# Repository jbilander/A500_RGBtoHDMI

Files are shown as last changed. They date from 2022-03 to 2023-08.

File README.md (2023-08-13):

# A500_RGBtoHDMI
My RGBtoHDMI-adapter-board design for A500.

***

<a href="images/A500_RGBtoHDMI_pic1.png">
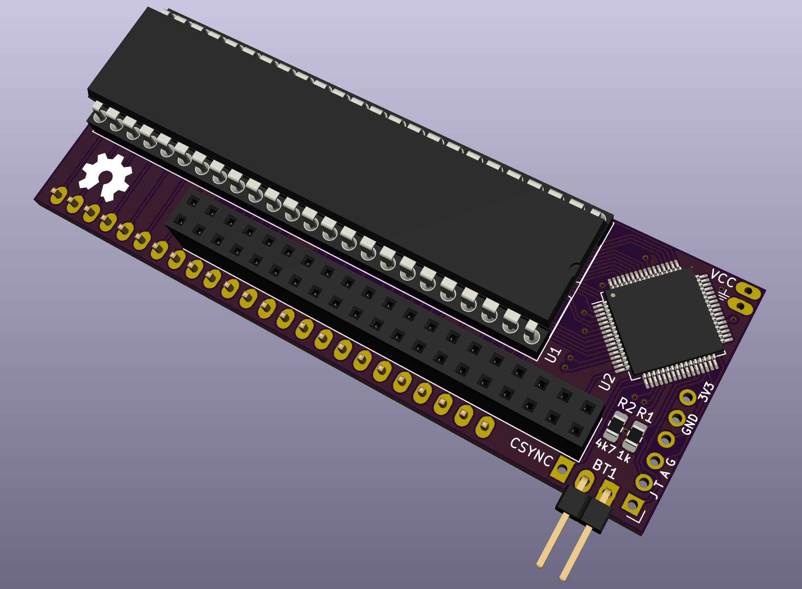
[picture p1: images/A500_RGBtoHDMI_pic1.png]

</a>
<a href="images/A500_RGBtoHDMI_pic2.png">
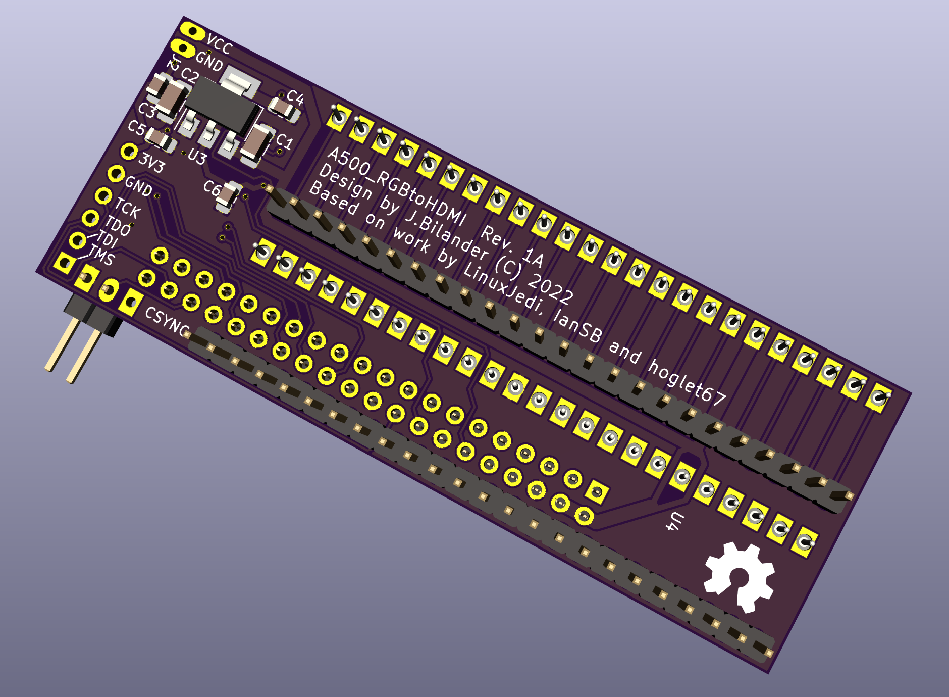
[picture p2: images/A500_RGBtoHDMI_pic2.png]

</a>
<br />
<a href="images/A500_RGBtoHDMI_pic5.png">
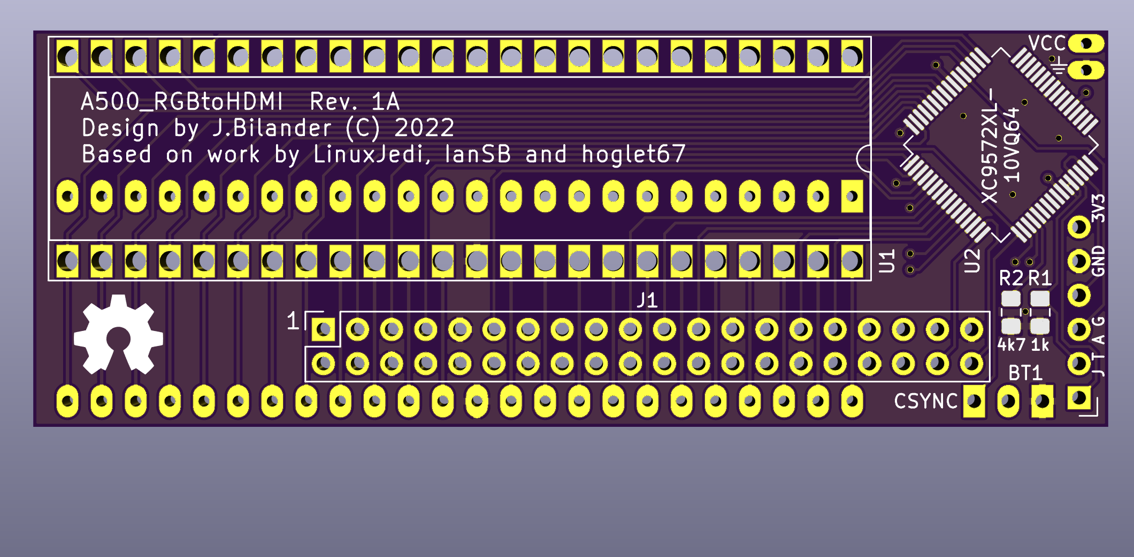
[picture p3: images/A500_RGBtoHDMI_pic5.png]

</a>
<a href="images/A500_RGBtoHDMI_pic6.png">
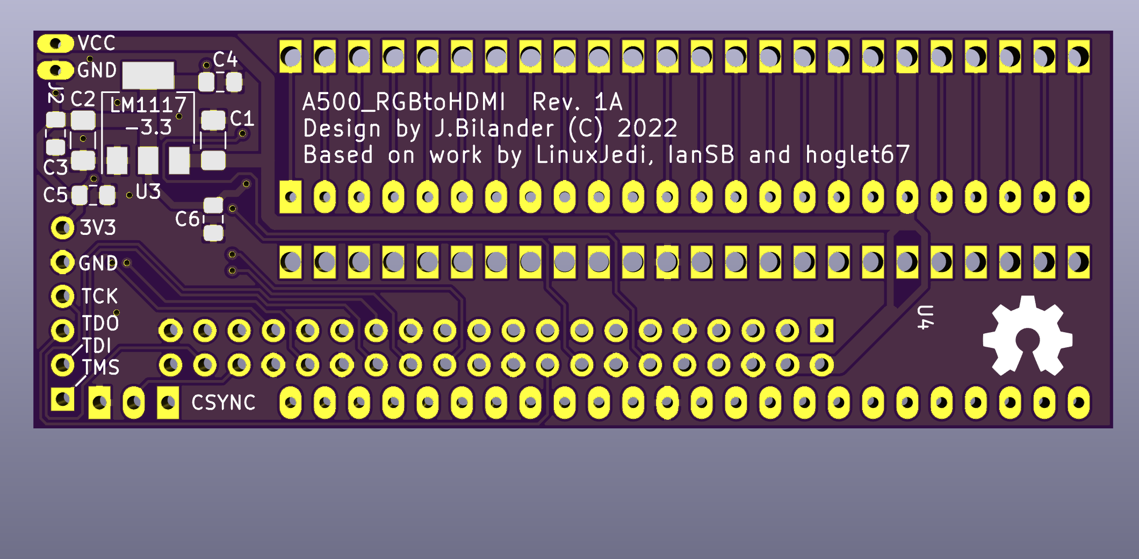
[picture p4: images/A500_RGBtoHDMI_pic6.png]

</a>

***

<a href="images/A500_RGBtoHDMI_pic8.png">
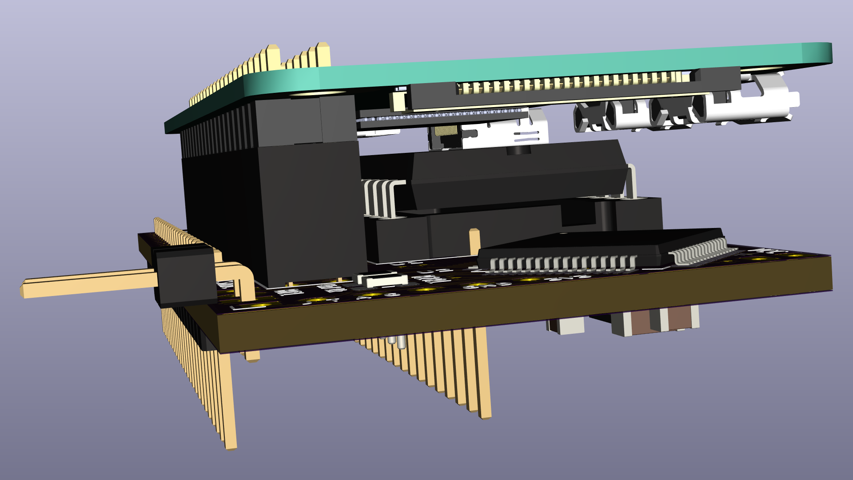
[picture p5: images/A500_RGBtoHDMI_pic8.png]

</a>
<a href="images/A500_RGBtoHDMI_pic9.png">
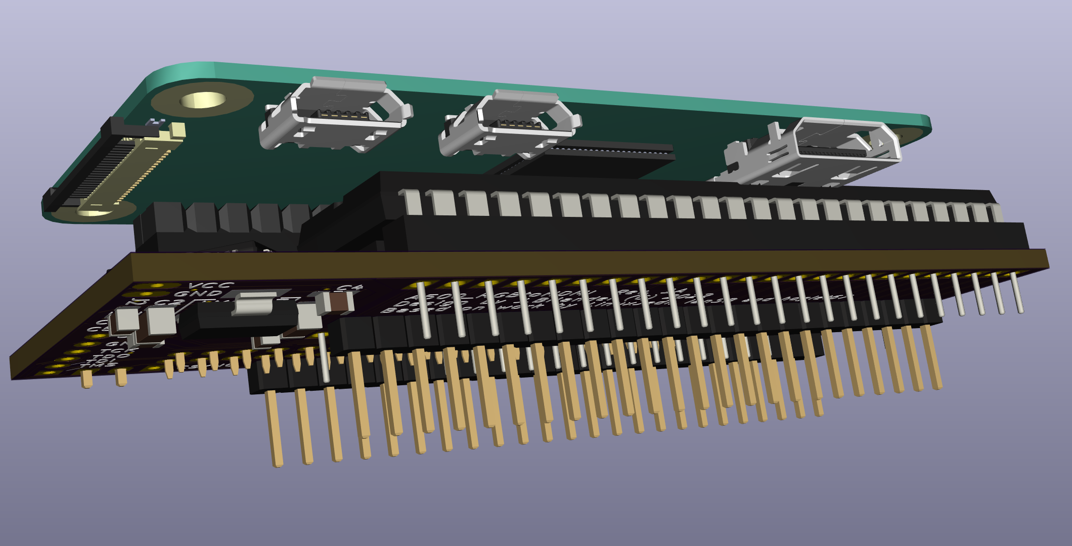
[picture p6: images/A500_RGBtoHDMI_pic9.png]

</a>
<br />
<a href="images/A500_RGBtoHDMI_pic10.png">
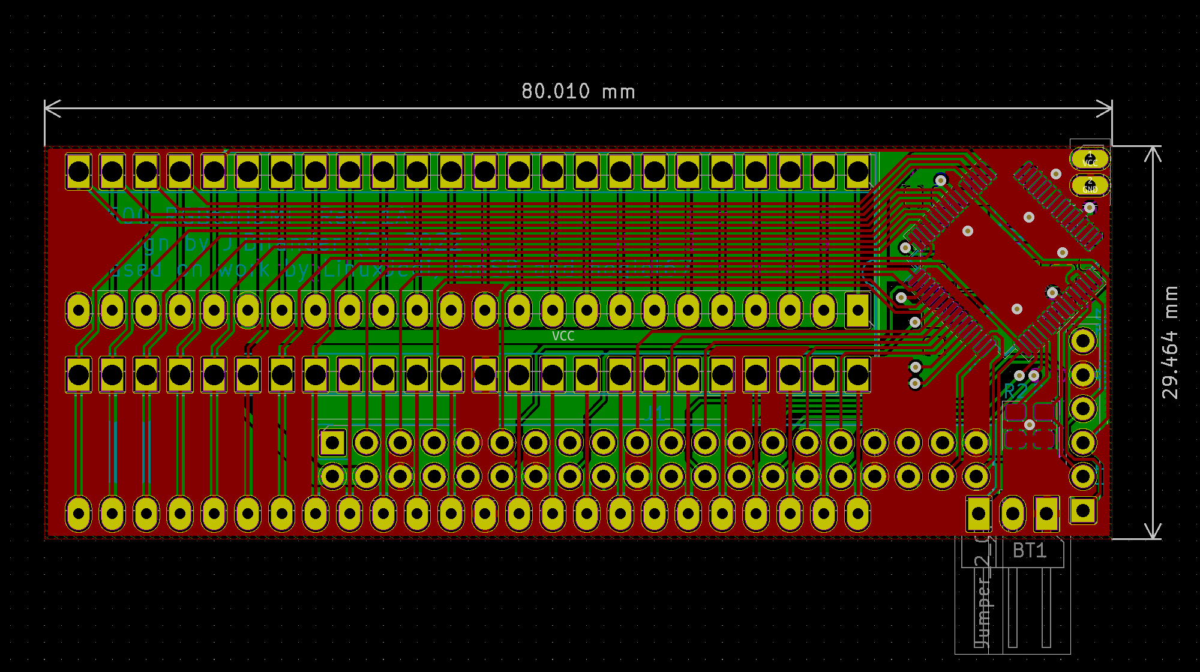
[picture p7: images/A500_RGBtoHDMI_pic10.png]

</a>

***

<a href="images/A500_RGBtoHDMI_pic11.jpg">
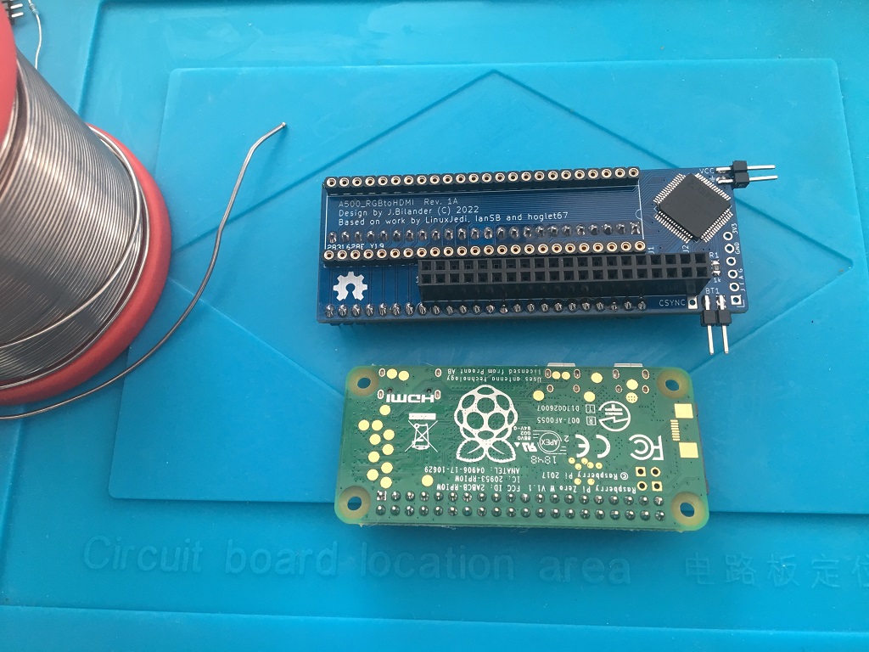
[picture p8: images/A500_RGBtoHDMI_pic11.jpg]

</a>
<a href="images/A500_RGBtoHDMI_pic13.jpg">
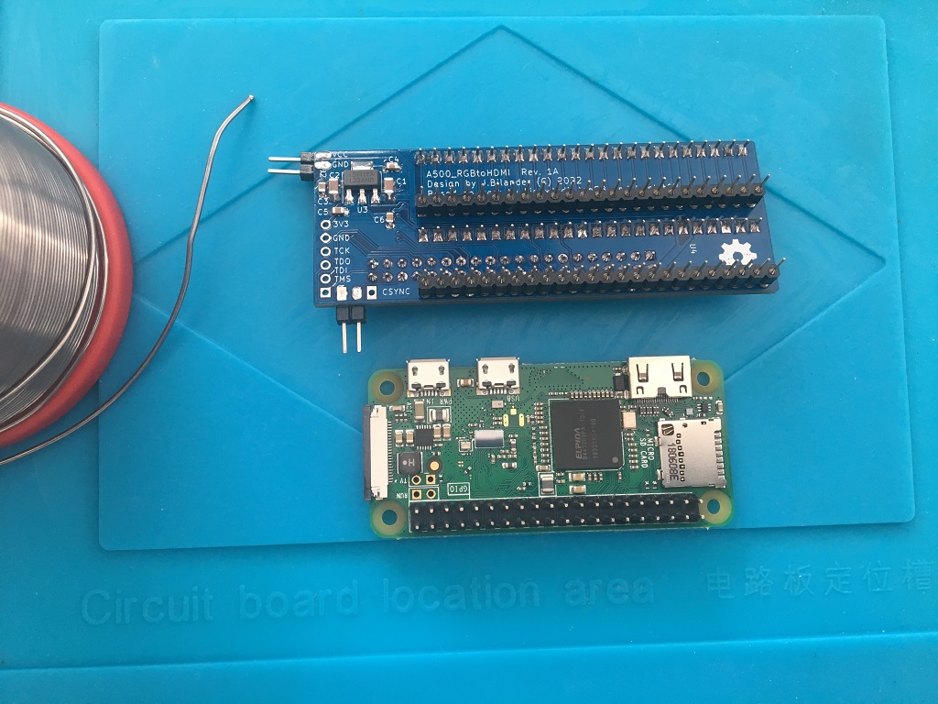
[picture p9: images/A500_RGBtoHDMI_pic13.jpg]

</a>
<a href="images/A500_RGBtoHDMI_pic12.jpg">
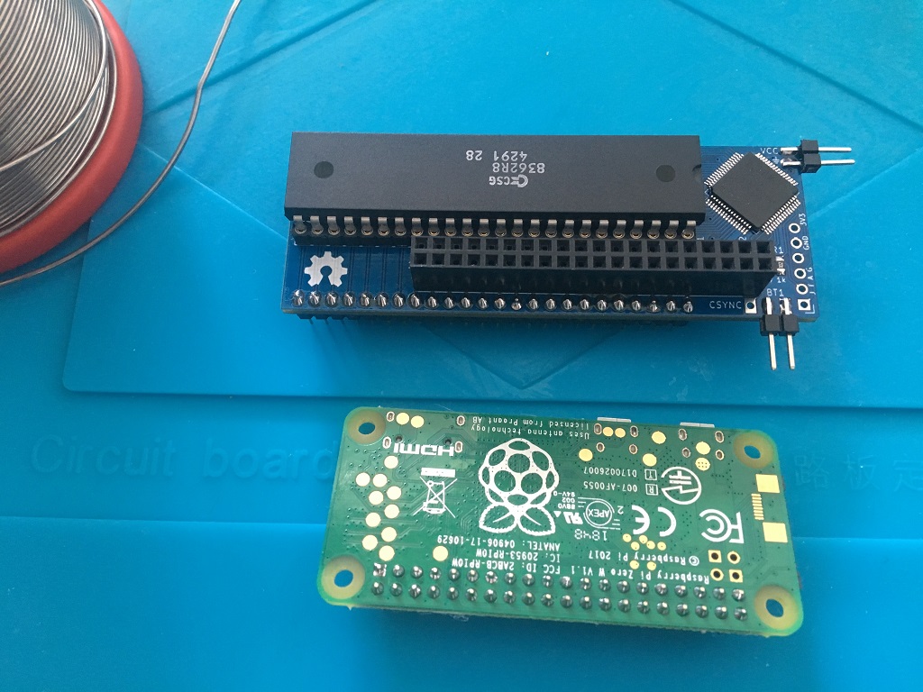
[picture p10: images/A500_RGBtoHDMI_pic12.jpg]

</a>
<br />
<a href="images/A500_RGBtoHDMI_pic14.jpg">
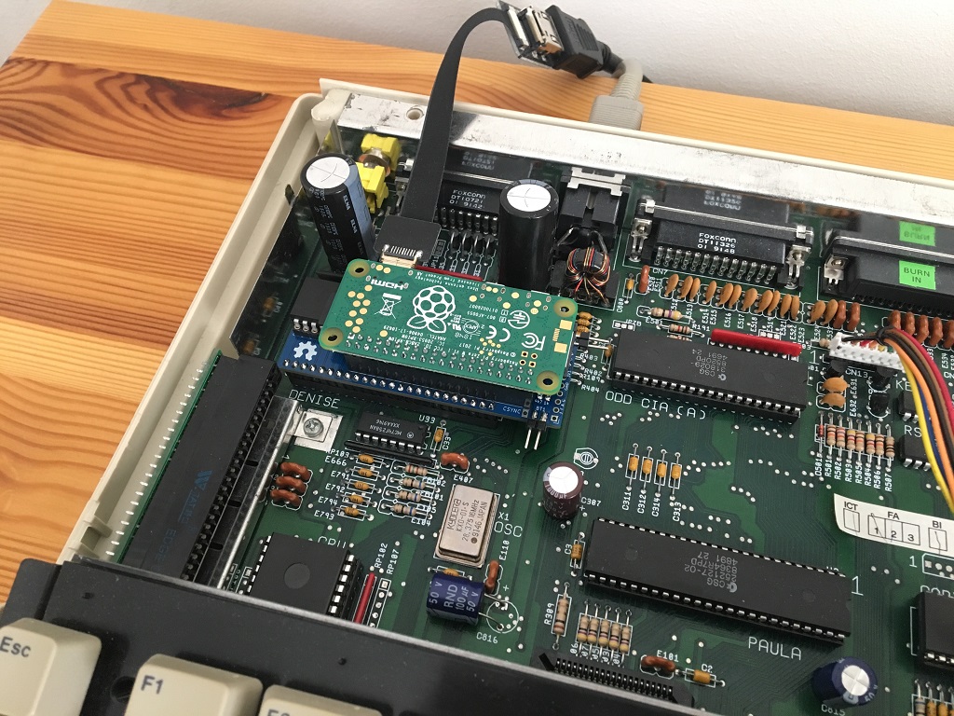
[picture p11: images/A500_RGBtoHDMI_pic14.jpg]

</a>
<a href="images/A500_RGBtoHDMI_pic30.jpg">
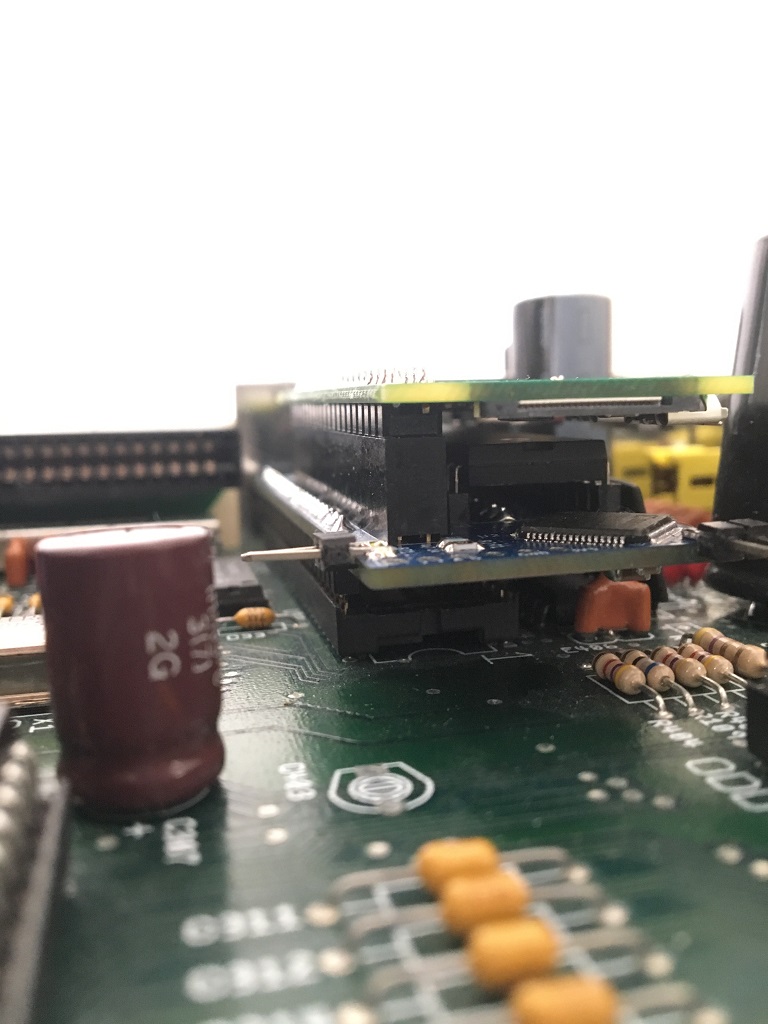
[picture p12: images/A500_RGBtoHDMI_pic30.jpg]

</a>

***

### Build

<a href="images/A500_RGBtoHDMI_pic15.jpg">
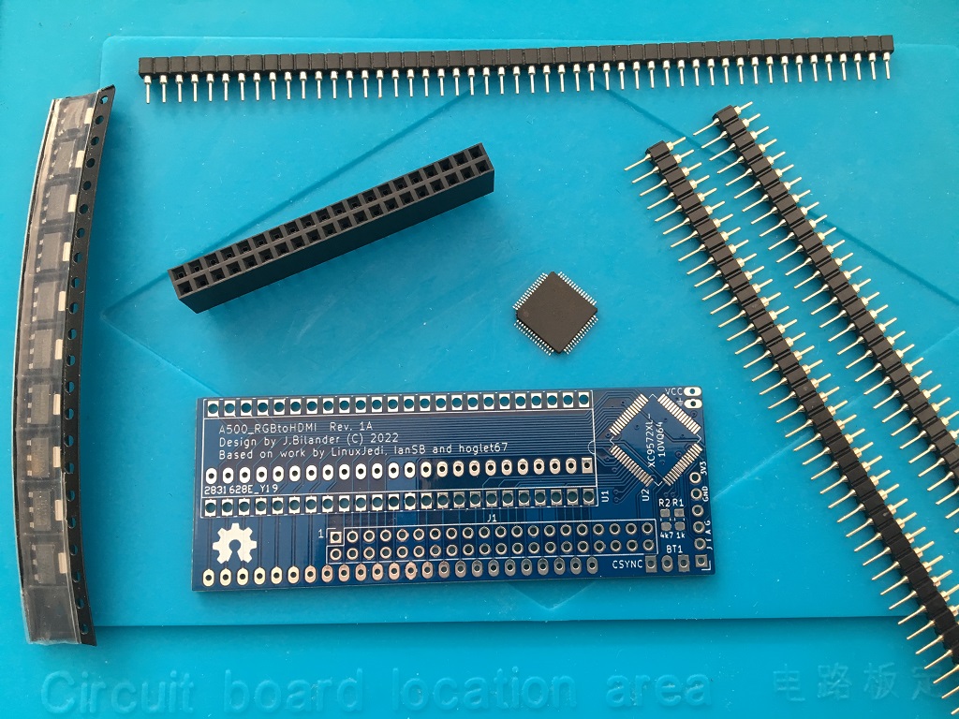
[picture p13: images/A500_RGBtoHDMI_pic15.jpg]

</a>
<a href="images/A500_RGBtoHDMI_pic17.jpg">
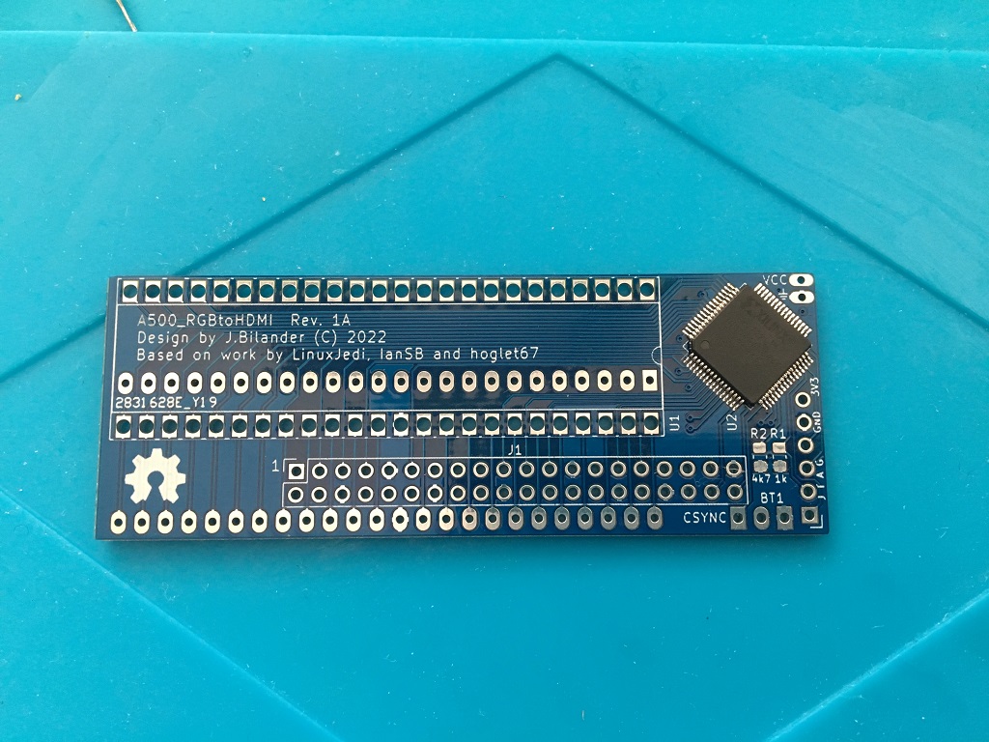
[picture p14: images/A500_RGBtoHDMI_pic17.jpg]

</a>
<a href="images/A500_RGBtoHDMI_pic18.jpg">
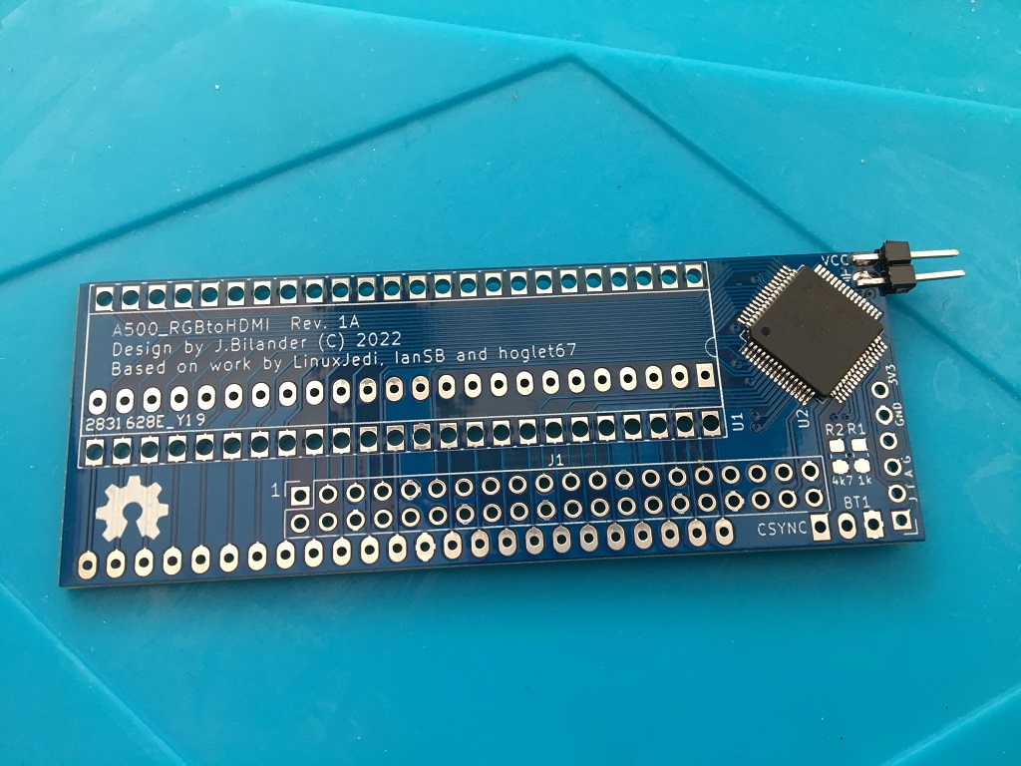
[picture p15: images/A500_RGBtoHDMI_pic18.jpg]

</a>
<br />
<a href="images/A500_RGBtoHDMI_pic19.jpg">
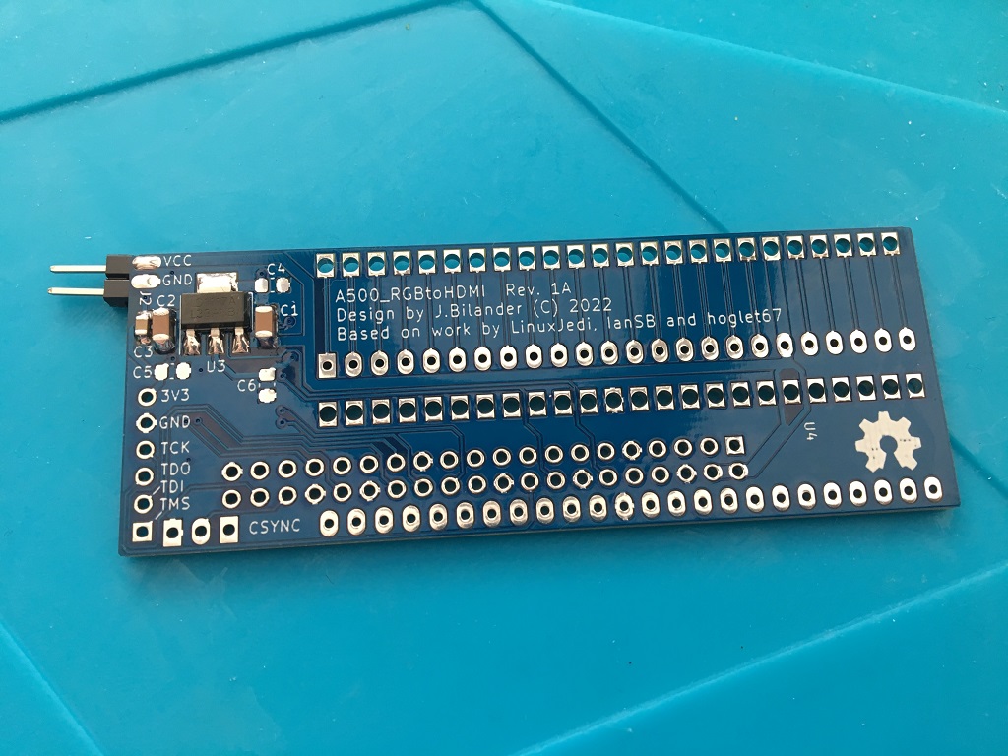
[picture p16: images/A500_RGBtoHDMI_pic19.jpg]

</a>
<a href="images/A500_RGBtoHDMI_pic20.jpg">
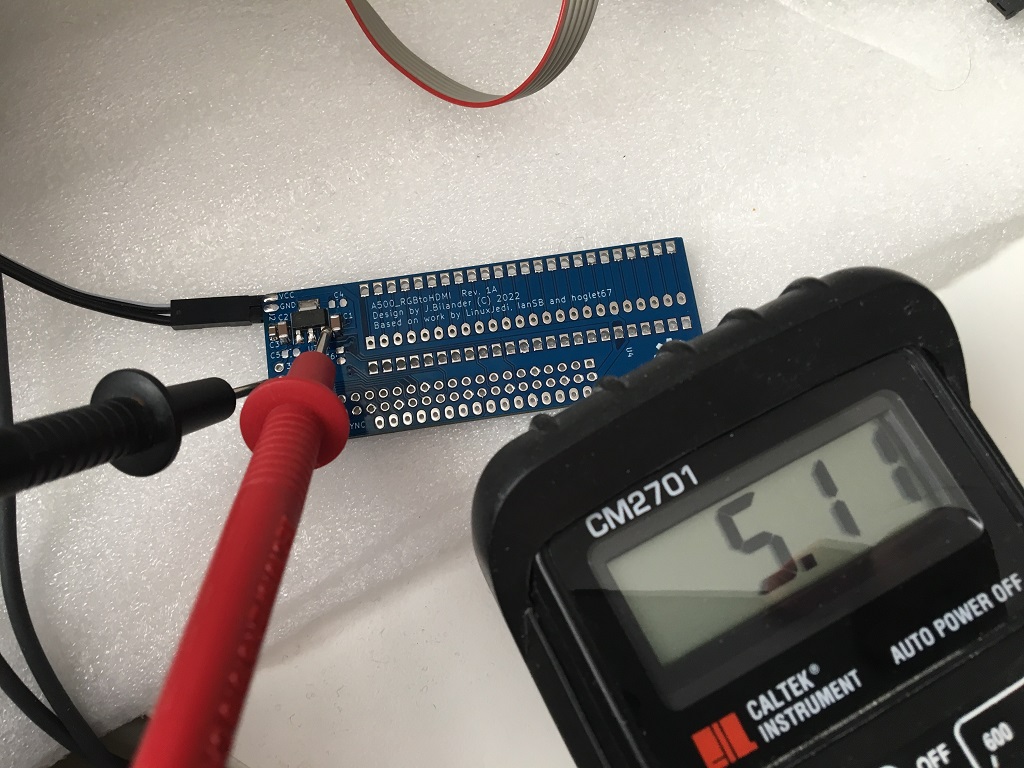
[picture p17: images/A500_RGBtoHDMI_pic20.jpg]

</a>
<a href="images/A500_RGBtoHDMI_pic21.jpg">
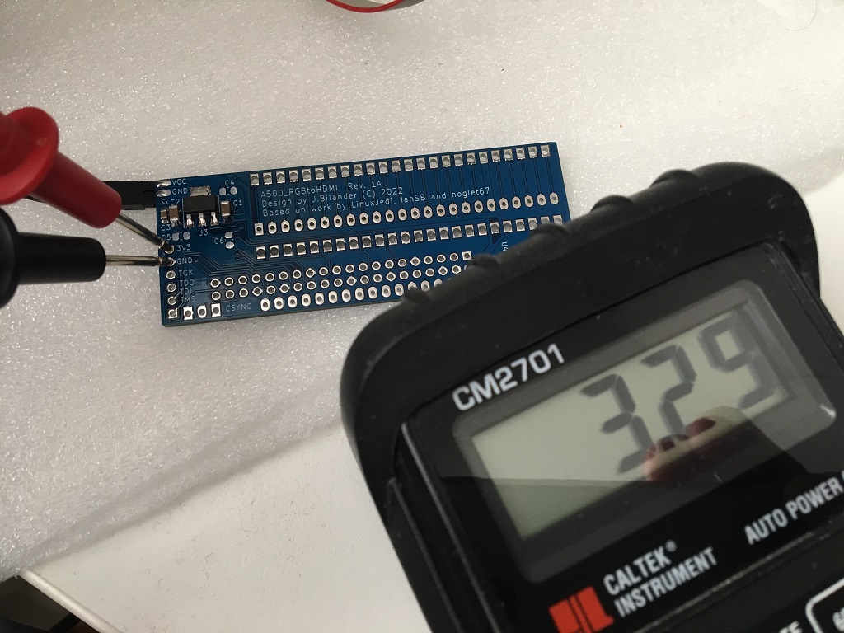
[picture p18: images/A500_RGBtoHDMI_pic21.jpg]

</a>
<br />
<a href="images/A500_RGBtoHDMI_pic22.jpg">
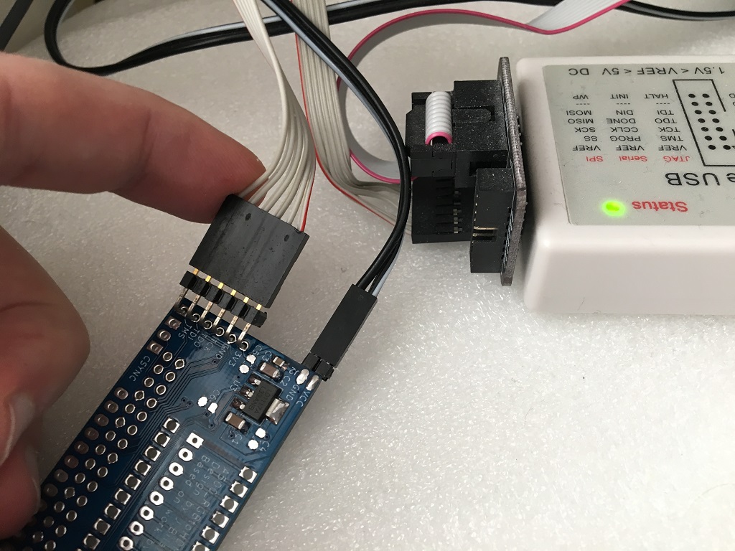
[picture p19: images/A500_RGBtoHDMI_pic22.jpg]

</a>
<a href="images/A500_RGBtoHDMI_pic23.jpg">
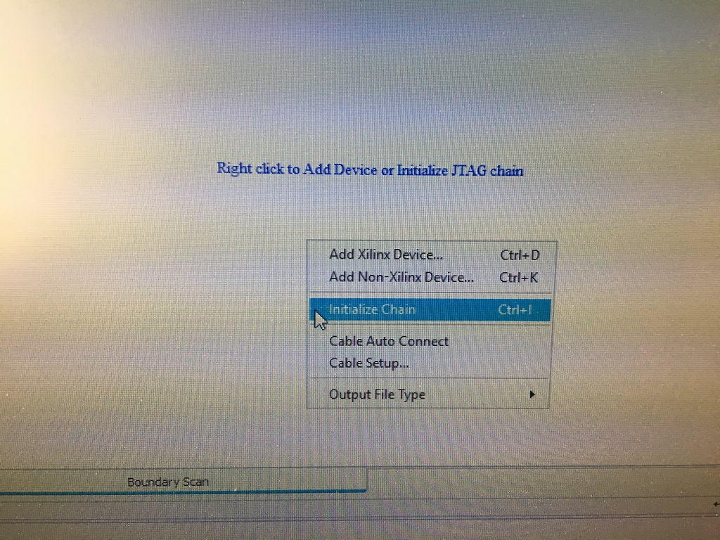
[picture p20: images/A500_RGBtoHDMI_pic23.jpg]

</a>
<a href="images/A500_RGBtoHDMI_pic24.jpg">
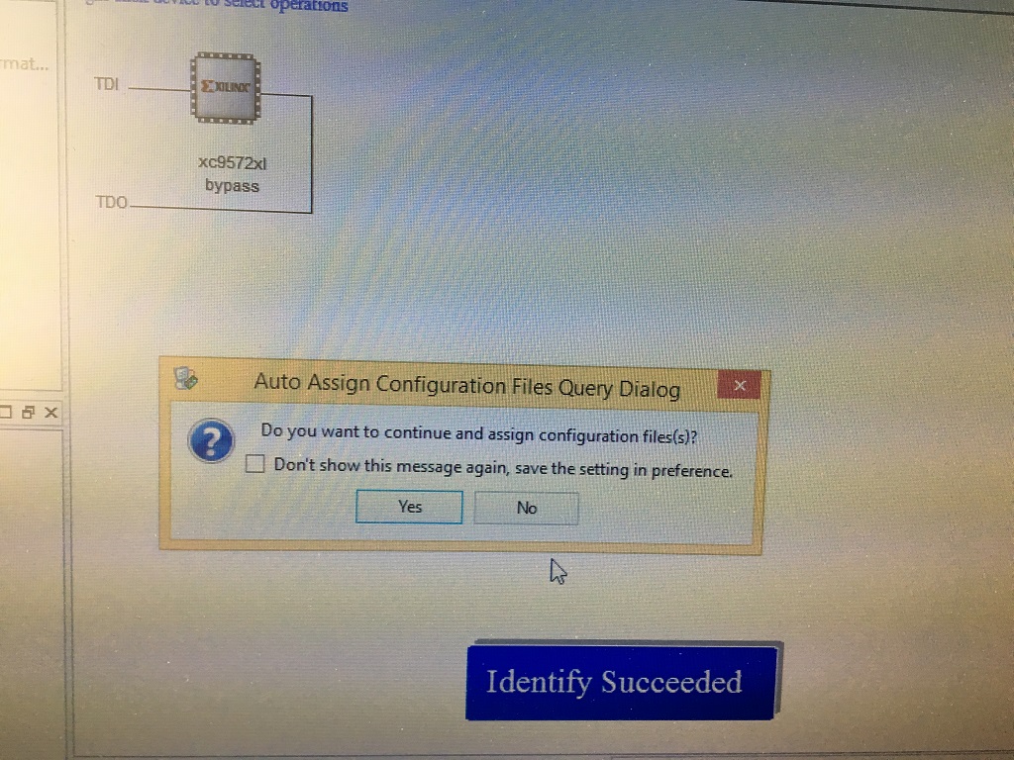
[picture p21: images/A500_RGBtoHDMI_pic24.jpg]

</a>
<br />
<a href="images/A500_RGBtoHDMI_pic25.jpg">
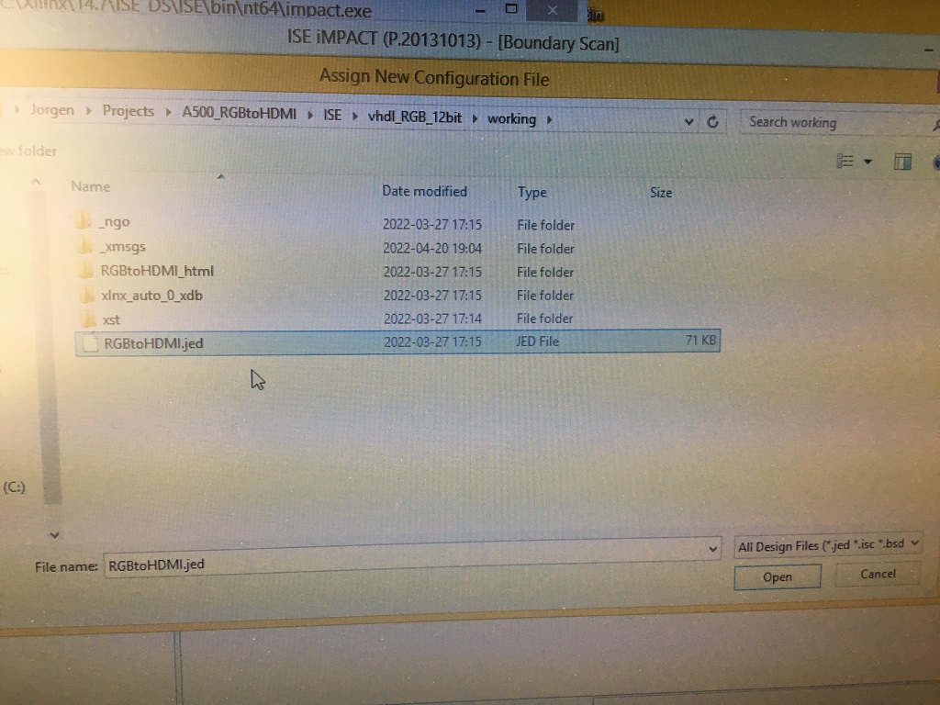
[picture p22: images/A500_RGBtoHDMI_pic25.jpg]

</a>
<a href="images/A500_RGBtoHDMI_pic26.jpg">
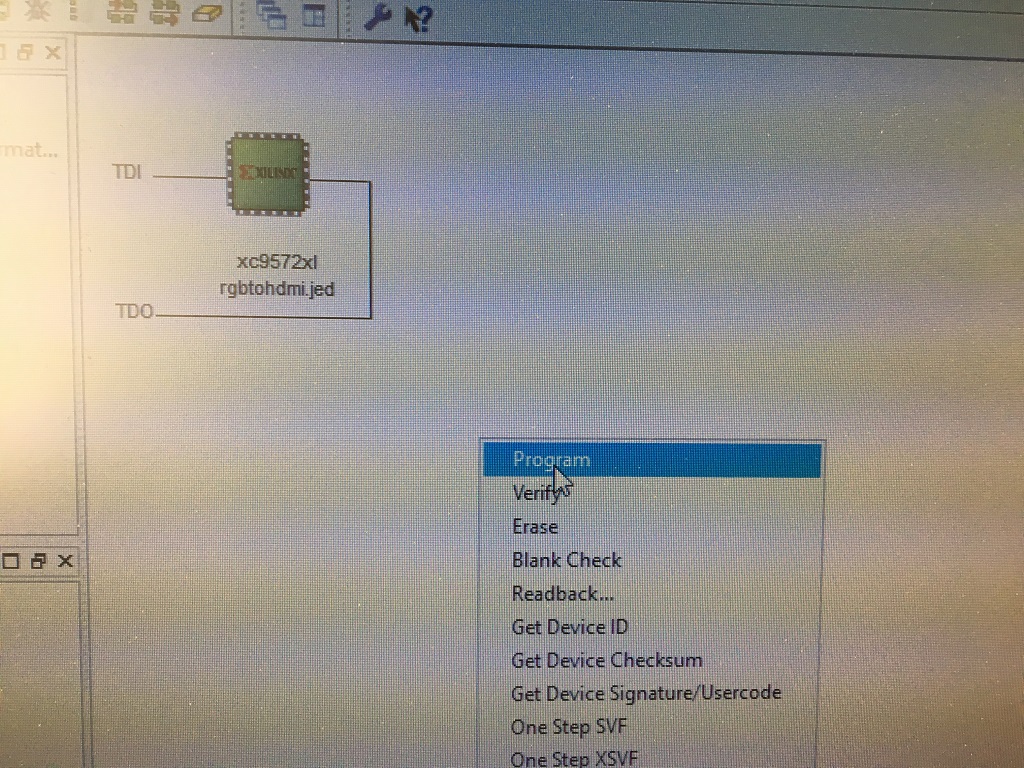
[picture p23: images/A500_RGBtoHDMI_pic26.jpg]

</a>
<a href="images/A500_RGBtoHDMI_pic27.jpg">
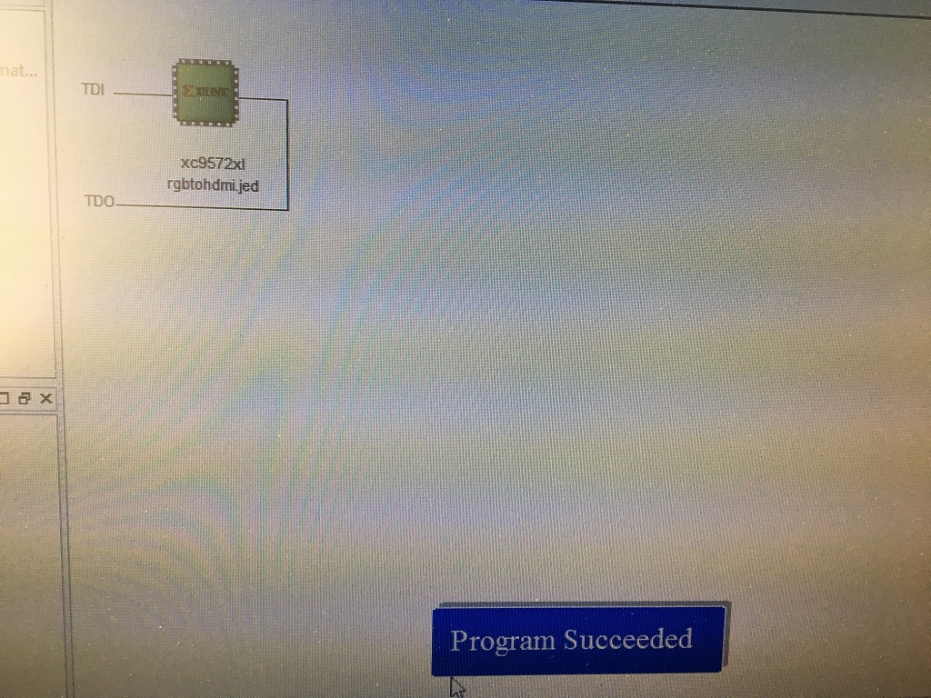
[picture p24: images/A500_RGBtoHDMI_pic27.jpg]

</a>
<br />
<a href="images/A500_RGBtoHDMI_pic28.jpg">
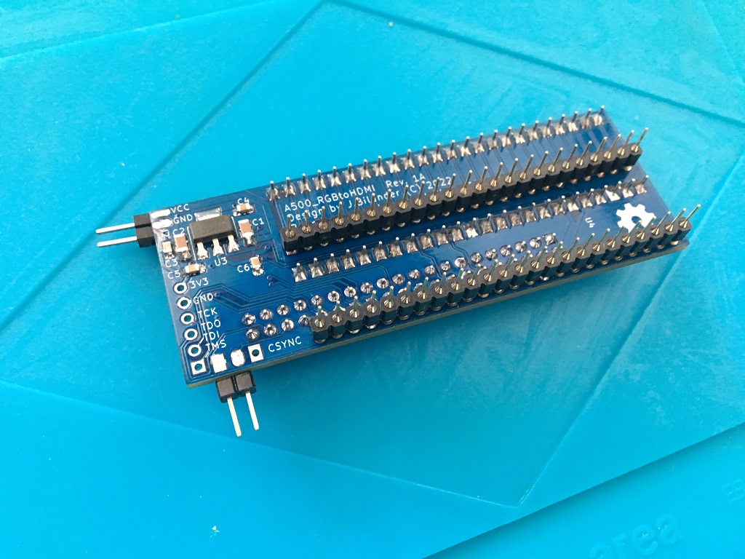
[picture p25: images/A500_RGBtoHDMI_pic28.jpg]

</a>
<a href="images/A500_RGBtoHDMI_pic29.jpg">
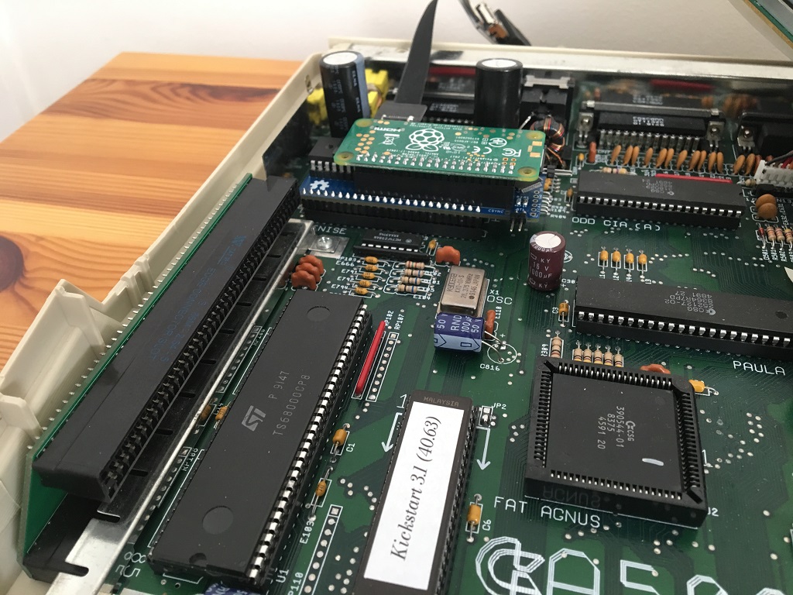
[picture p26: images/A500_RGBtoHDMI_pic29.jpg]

</a>
<a href="images/A500_RGBtoHDMI_pic31.jpg">
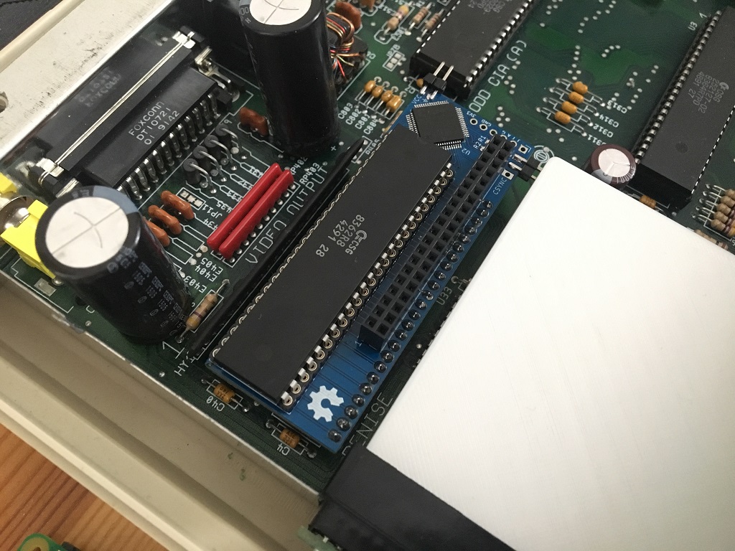
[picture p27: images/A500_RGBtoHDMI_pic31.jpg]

</a>
<br />
<a href="images/A500_RGBtoHDMI_pic32.jpg">
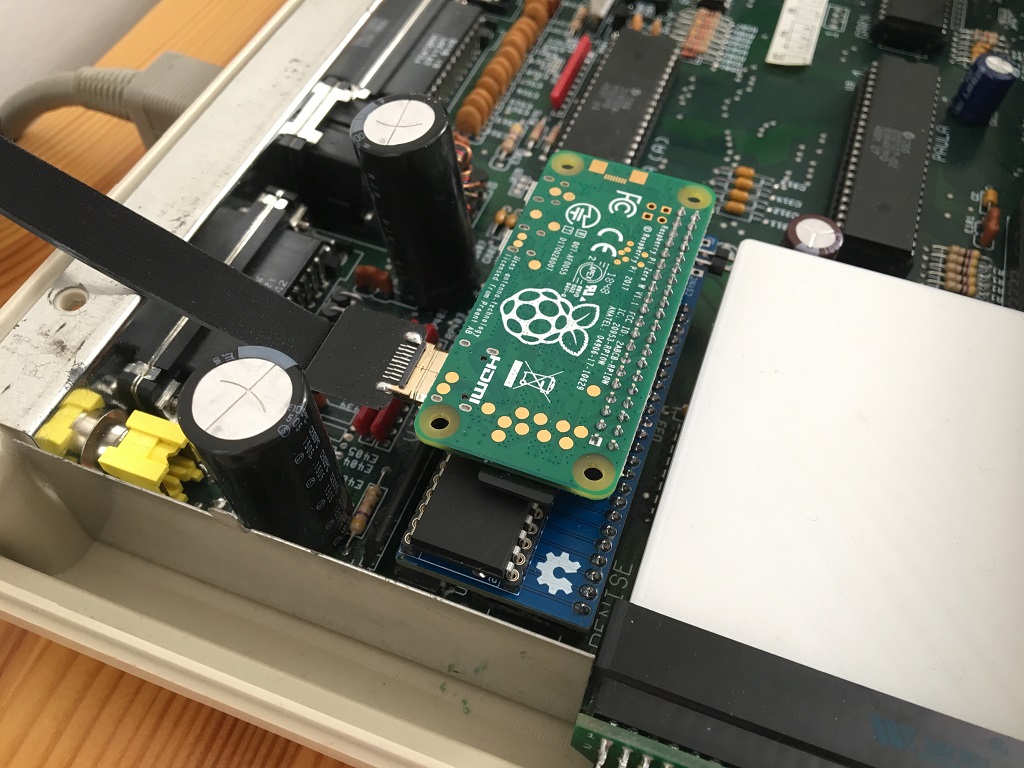
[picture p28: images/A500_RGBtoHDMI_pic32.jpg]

</a>
<a href="images/A500_RGBtoHDMI_pic33.jpg">
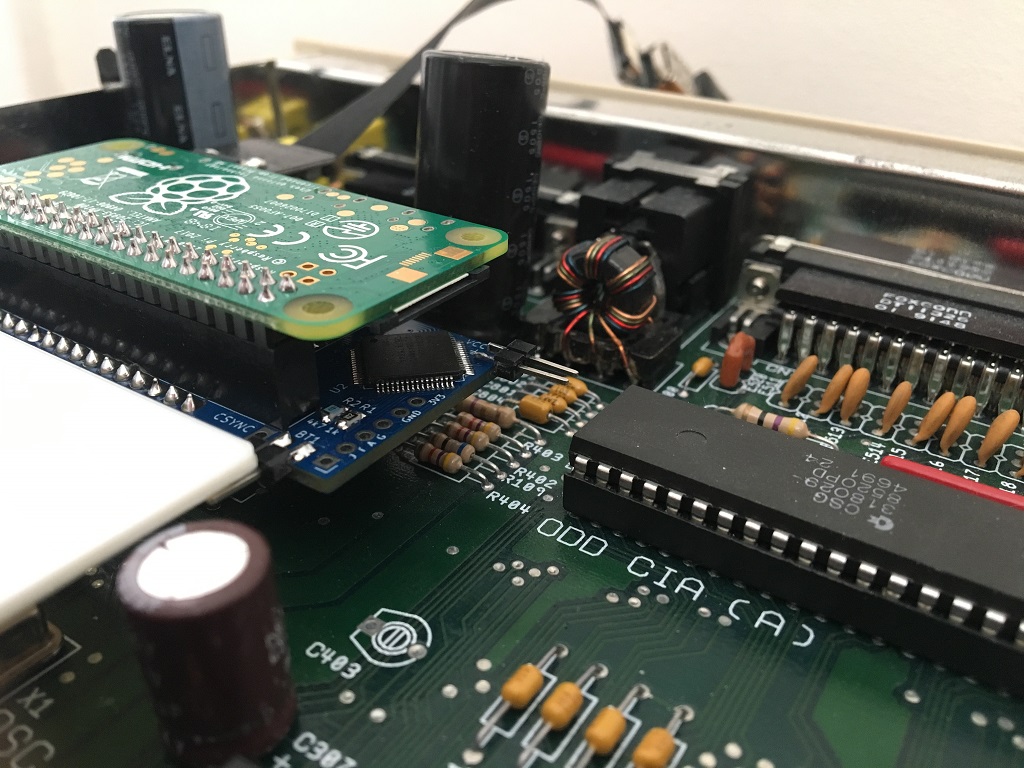
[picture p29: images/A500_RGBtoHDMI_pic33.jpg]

</a>
<a href="images/A500_RGBtoHDMI_pic35.jpg">
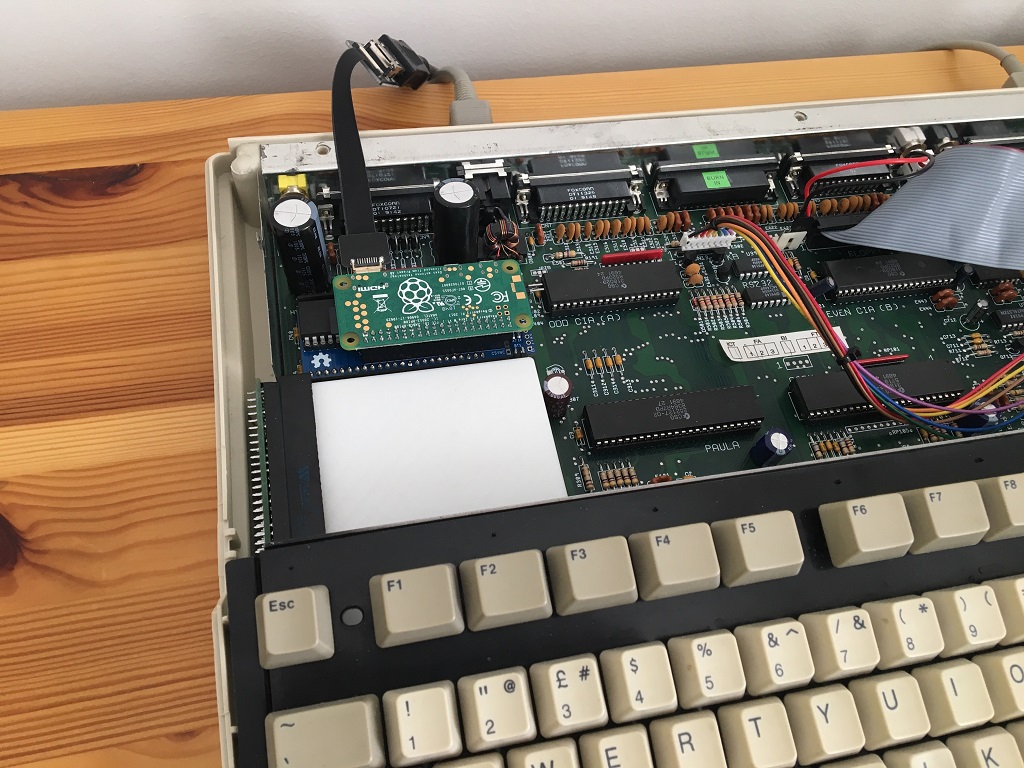
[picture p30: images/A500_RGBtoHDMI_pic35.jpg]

</a>
<br />
<a href="images/A500_RGBtoHDMI_pic36.jpg">
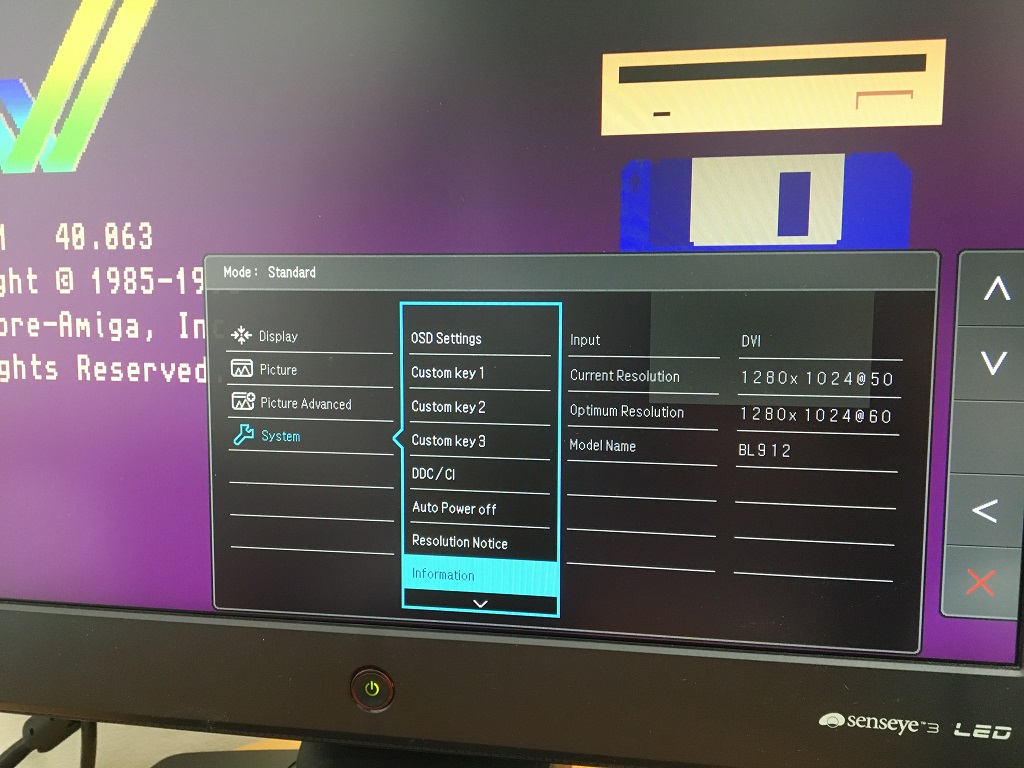
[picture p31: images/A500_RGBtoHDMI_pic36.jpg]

</a>
<a href="images/A500_RGBtoHDMI_pic37.jpg">
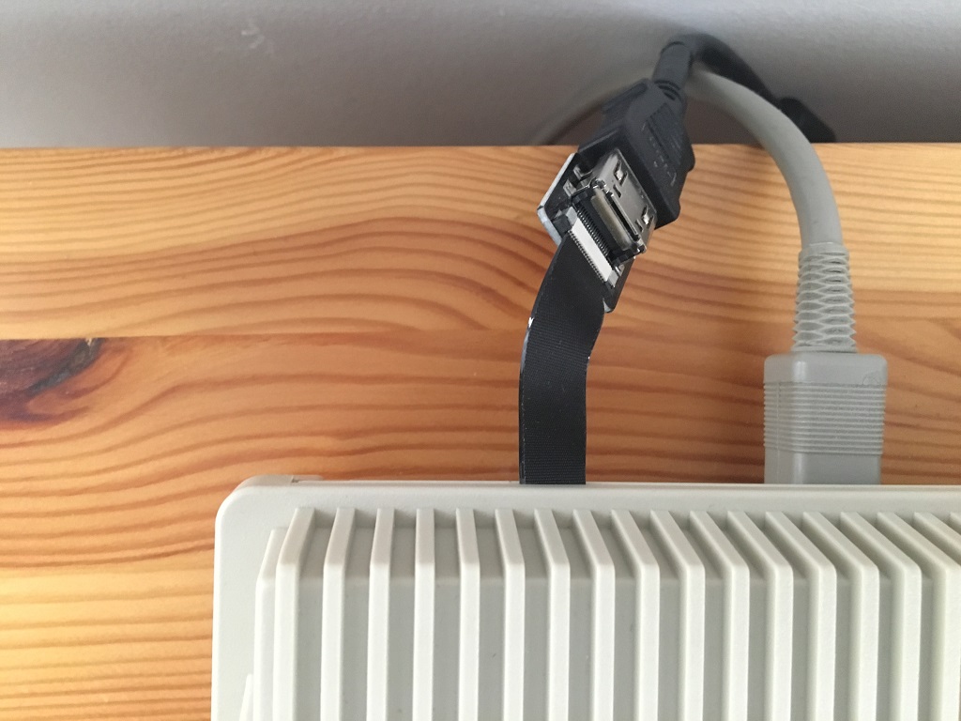
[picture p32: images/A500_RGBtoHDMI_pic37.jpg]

</a>
<a href="images/A500_RGBtoHDMI_pic38.jpg">
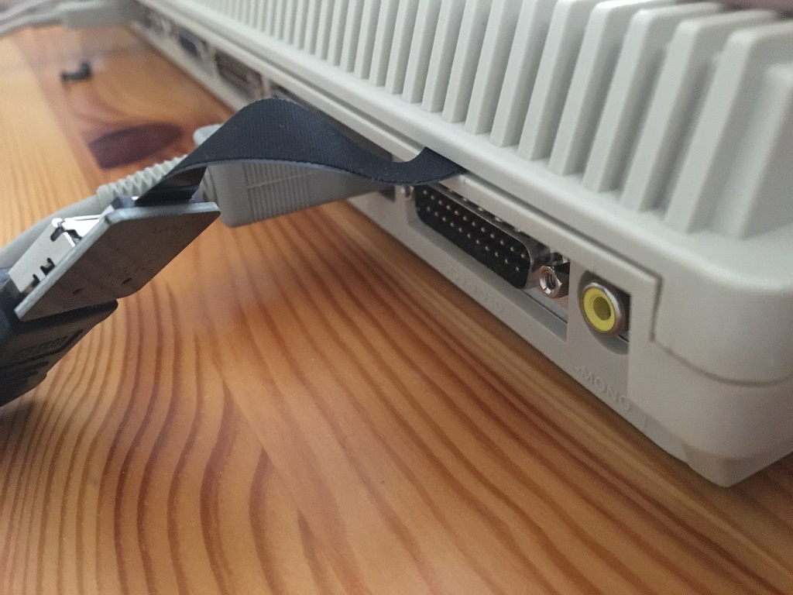
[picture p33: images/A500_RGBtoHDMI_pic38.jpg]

</a>

***

Video: <br />

https://drive.google.com/file/d/1ksP-LVyoxUxEtZK_JW-vs8qUCuZv387j/view?usp=sharing

***

### RPi Zero configuration

Follow the instructions here:

https://github.com/hoglet67/RGBtoHDMI/wiki/Quick-Start-Guide#installing-the-software

...and then...

To auto configure for correct profile and operation with single button, copy the files in the appropriate Amiga folder into the root folder, overwriting any existing files.

<a href="images/RPi_firmware_and_config.jpg">
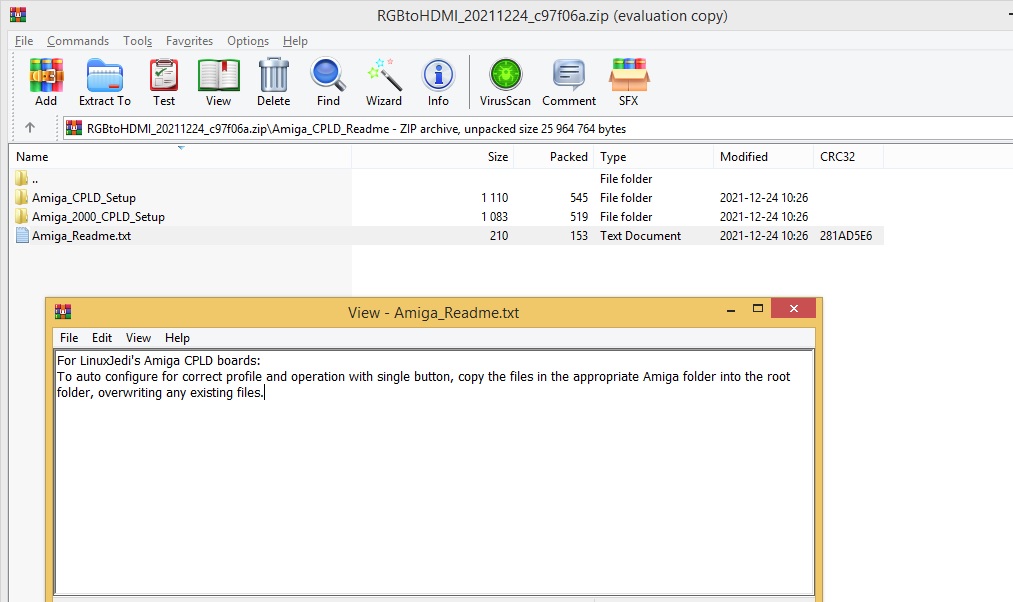
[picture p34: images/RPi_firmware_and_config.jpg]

</a>

***

BOM Rev. 1A
---------
Position  | Name/Value   | Package | Notes
-|-|-|-|
U1 | 2x24 Round Female Pin Header Connector | 1x40 2.54mm pitch | Cut down to 2x24 Pin for socketing Denise
U2 | XC9572XL-10VQ64 | VQFP-64 | Xilinx 72-mc CPLD 52 I/O
U3 | LM1117-3.3 or AMS1117-3.3 | SOT-223 | 3.3V 1A Low Drop-Out (LDO) Voltage regulator.
U4 | 2x24 Single Row Male Pin Connector Strip | 1x40 2.54mm pitch | Cut down to 2x24 Pin
J1 | 2X20 Pin Double Row Straight Female Pin Header 2.54mm pitch | 2x20 2.54mm pitch | [2x20 Pin Header](https://www.aliexpress.com/item/32854215610.html)
R1 | 1k | 0805 | Pull-down resistor (SPDATA)
R2 | 4.7k | 0805 | Pull-down resistor (DETECT)
C1 | 10uF | 1206 | 5V Decoupling capacitor
C2 | 10uF | 1206 | 3V3 Decoupling capacitor
C3 | 0.1uF = 100nF | 0805 | 3V3 Decoupling capacitor
C4 | 0.1uF = 100nF | 0805 | 3V3 Decoupling capacitor
C5 | 0.1uF = 100nF | 0805 | 3V3 Decoupling capacitor
C6 | 0.1uF = 100nF | 0805 | 3V3 Decoupling capacitor
JTAG | JTAG Pin Header | 2.54mm pitch | (Optional) Hold JTAG-header against holes while programming is enough.
PWR | VCC/GND-header | 2.00mm pitch | A 2.54mm two-pin header fits surface mounted on pads

Cable:
Ribbon FPV HDMI-Compatible Connector Flexible Flat Cable<br />
https://www.aliexpress.com/item/4000014554460.html<br />
* FFC 10cm (or whatever length you prefer, cable on pic is 10cm)<br />
* Connector-A4<br />
* Connector-C1<br />

***

Happy Hackin'

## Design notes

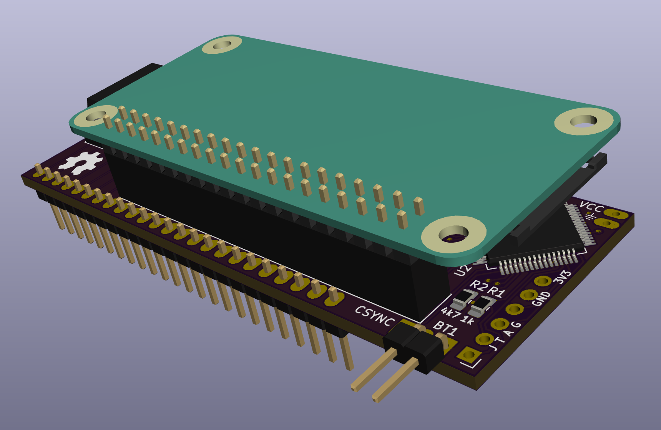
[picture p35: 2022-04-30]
images/A500_RGBtoHDMI_pic7.png

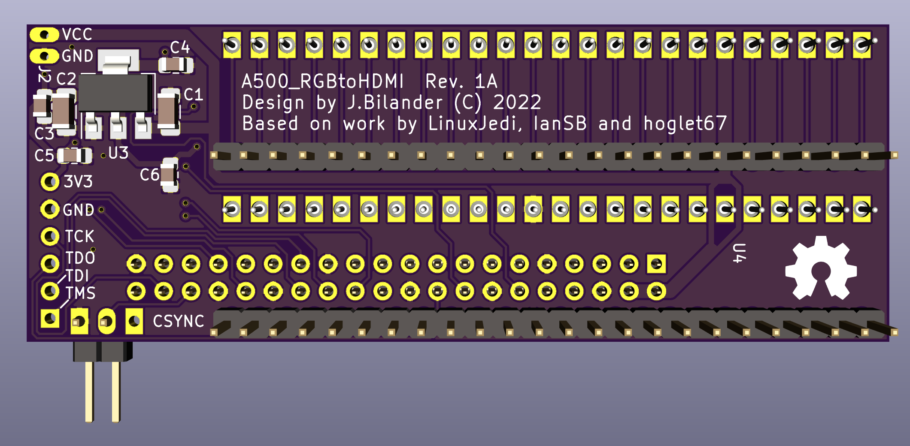
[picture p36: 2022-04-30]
images/A500_RGBtoHDMI_pic4.png

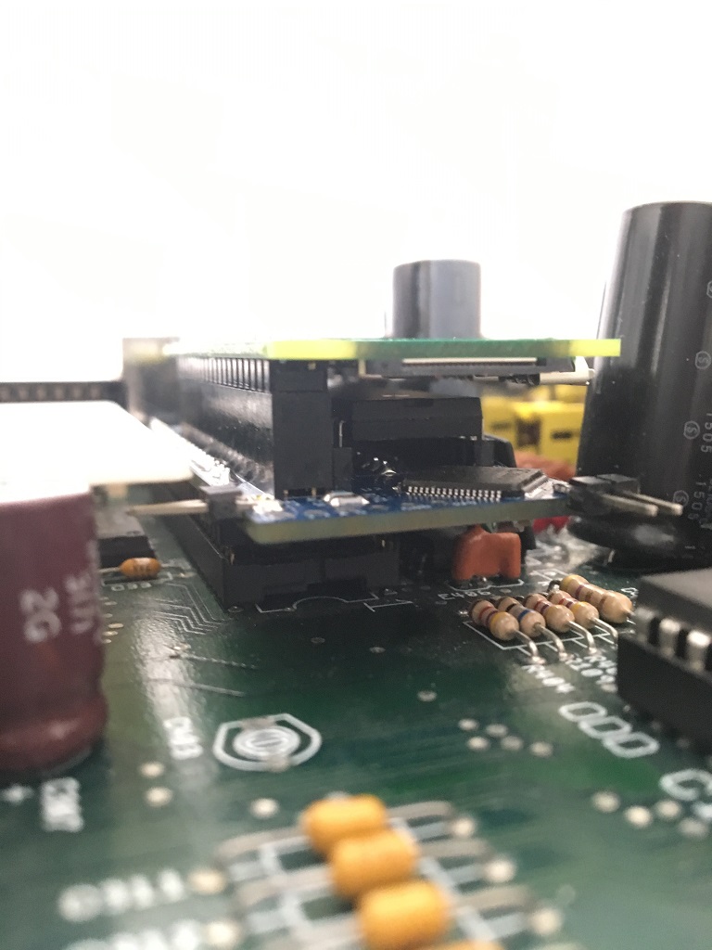
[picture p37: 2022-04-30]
images/A500_RGBtoHDMI_pic34.jpg

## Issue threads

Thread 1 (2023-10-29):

RGB to HDMI green screen

nbdy32, 2023-10-29:
Hi, have a green screen when turning A500 on ...

The PI works ... tested with another RGB to HDMI ...

Denise works ... also tested with another RGB to HDMI ...

Program - all passed and succesfull ...

SD card - all the same in all testings ... working ...

Any advice, where to look, rechecked the board but didn't find any thing that is not soldered OK ...

THX

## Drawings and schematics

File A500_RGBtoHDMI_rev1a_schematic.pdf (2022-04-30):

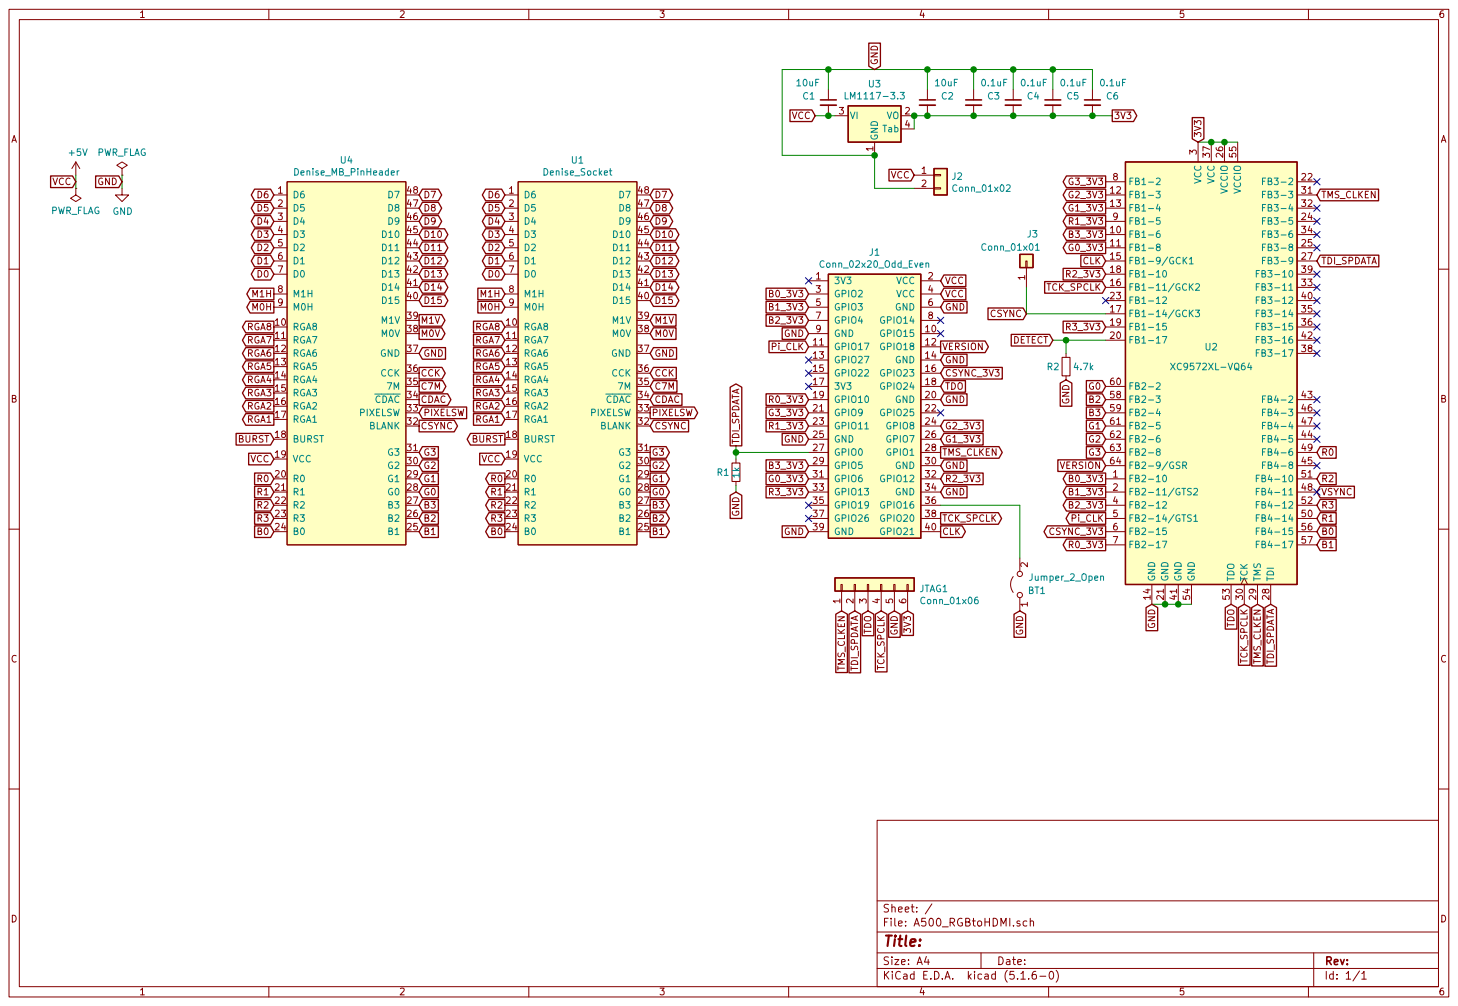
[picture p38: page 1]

3 TCK 30 FB3-3 31 FB3-4 32 FB3-11 33 FB3-6 34 FB3-14 35 FB3-15 36 VCC 37 FB3-17 38 FB3-10 39 FB2-12 4 FB3-12 40 GND 41 FB3-16 42 FB4-2 43 FB4-5 44 FB4-8 45 FB4-3 46 FB4-4 47 FB4-11 48 FB4-6 49 FB2-14/GTS1 5 FB4-14 50 FB4-10 51 FB4-12 52 TDO 53 GND 54 VCCIO 55 FB4-15 56 FB4-17 57 FB2-3 58 FB2-4 59 FB2-15 6 FB2-2 60 FB2-5 61 FB2-6 62 FB2-8 63 FB2-9/GSR 64 FB2-17 7 FB1-2 8 FB1-5 9 U2 XC9572XL-VQ64

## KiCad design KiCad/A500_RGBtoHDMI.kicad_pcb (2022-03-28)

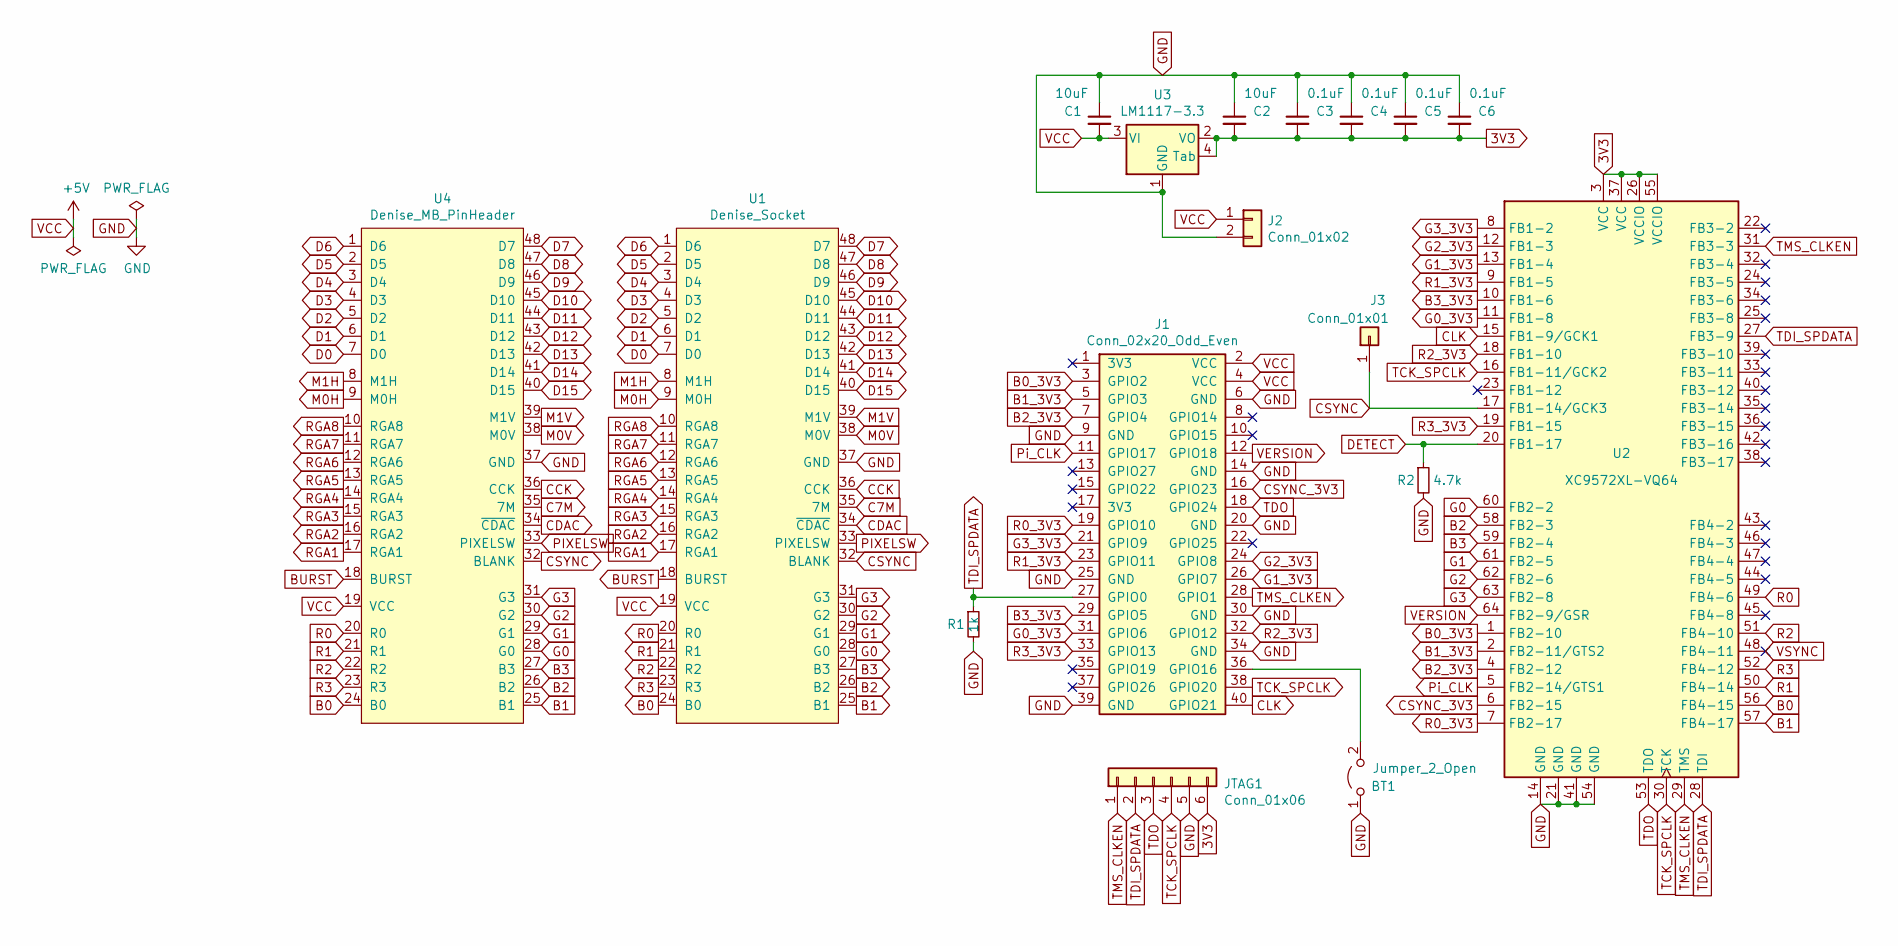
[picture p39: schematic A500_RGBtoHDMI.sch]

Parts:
BT1: Jumper_2_Open; PinHeader_1x02_P2.54mm_Horizontal
C1, C2: 10uF; C_1206_3216Metric_Pad1.42x1.75mm_HandSolder
C3, C4, C5, C6: 0.1uF; C_0805_2012Metric_Pad1.15x1.40mm_HandSolder
J1: Conn_02x20_Odd_Even; PinSocket_2x20_P2.54mm_Vertical
J2: Conn_01x02; PinHeader_1x02_P2.00mm_Vertical
J3: Conn_01x01; PinHeader_1x01_P2.54mm_Horizontal
JTAG1: Conn_01x06; PinHeader_1x06_P2.54mm_Vertical
R1: 1k; R_0805_2012Metric_Pad1.15x1.40mm_HandSolder
R2: 4.7k; R_0805_2012Metric_Pad1.15x1.40mm_HandSolder
U1: Denise_Socket; DIP-48_W15.24mm_Socket_LongPads
U2: XC9572XL-VQ64; TQFP-64_10x10mm_P0.5mm
U3: LM1117-3.3; SOT-223
U4: Denise_MB_PinHeader; DIP-48_W15.24mm_LongPads

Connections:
3V3: C2.2, C3.2, C4.2, C5.2, C6.2, JTAG1.6, U2.3 (VCC), U2.26 (VCCIO), U2.37 (VCC), U2.55 (VCCIO), U3.2 (VO), U3.4 (Tab)
B0: U1.24 (B0), U2.56 (FB4-15), U4.24 (B0)
B0_3V3: J1.3 (GPIO2), U2.1 (FB2-10)
B1: U1.25 (B1), U2.57 (FB4-17), U4.25 (B1)
B1_3V3: J1.5 (GPIO3), U2.2 (FB2-11/GTS2)
B2: U1.26 (B2), U2.58 (FB2-3), U4.26 (B2)
B2_3V3: J1.7 (GPIO4), U2.4 (FB2-12)
B3: U1.27 (B3), U2.59 (FB2-4), U4.27 (B3)
B3_3V3: J1.29 (GPIO5), U2.10 (FB1-6)
BURST: U1.18 (BURST), U4.18 (BURST)
C7M: U1.35 (7M), U4.35 (7M)
CCK: U1.36 (CCK), U4.36 (CCK)
CDAC: U1.34 (~CDAC), U4.34 (~CDAC)
CLK: J1.40 (GPIO21), U2.15 (FB1-9/GCK1)
CSYNC: J3.1, U1.32 (BLANK), U2.17 (FB1-14/GCK3), U4.32 (BLANK)
CSYNC_3V3: J1.16 (GPIO23), U2.6 (FB2-15)
D0: U1.7 (D0), U4.7 (D0)
D1: U1.6 (D1), U4.6 (D1)
D2: U1.5 (D2), U4.5 (D2)
D3: U1.4 (D3), U4.4 (D3)
D4: U1.3 (D4), U4.3 (D4)
D5: U1.2 (D5), U4.2 (D5)
D6: U1.1 (D6), U4.1 (D6)
D7: U1.48 (D7), U4.48 (D7)
D8: U1.47 (D8), U4.47 (D8)
D9: U1.46 (D9), U4.46 (D9)
D10: U1.45 (D10), U4.45 (D10)
D11: U1.44 (D11), U4.44 (D11)
D12: U1.43 (D12), U4.43 (D12)
D13: U1.42 (D13), U4.42 (D13)
D14: U1.41 (D14), U4.41 (D14)
D15: U1.40 (D15), U4.40 (D15)
DETECT: R2.1, U2.20 (FB1-17)
G0: U1.28 (G0), U2.60 (FB2-2), U4.28 (G0)
G0_3V3: J1.31 (GPIO6), U2.11 (FB1-8)
G1: U1.29 (G1), U2.61 (FB2-5), U4.29 (G1)
G1_3V3: J1.26 (GPIO7), U2.13 (FB1-4)
G2: U1.30 (G2), U2.62 (FB2-6), U4.30 (G2)
G2_3V3: J1.24 (GPIO8), U2.12 (FB1-3)
G3: U1.31 (G3), U2.63 (FB2-8), U4.31 (G3)
G3_3V3: J1.21 (GPIO9), U2.8 (FB1-2)
GND: BT1.1 (A), C1.1, C2.1, C3.1, C4.1, C5.1, C6.1, J1.6 (GND), J1.9 (GND), J1.14 (GND), J1.20 (GND), J1.25 (GND), J1.30 (GND), J1.34 (GND), J1.39 (GND), J2.2, JTAG1.5, R1.2, R2.2, U1.37 (GND), U2.14 (GND), U2.21 (GND), U2.41 (GND), U2.54 (GND), U3.1 (GND), U4.37 (GND)
M0H: U1.9 (M0H), U4.9 (M0H)
M0V: U1.38 (M0V), U4.38 (M0V)
M1H: U1.8 (M1H), U4.8 (M1H)
M1V: U1.39 (M1V), U4.39 (M1V)
unnamed: BT1.2 (B), J1.36 (GPIO16)
PIXELSW: U1.33 (PIXELSW), U4.33 (PIXELSW)
Pi_CLK: J1.11 (GPIO17), U2.5 (FB2-14/GTS1)
R0: U1.20 (R0), U2.49 (FB4-6), U4.20 (R0)
R0_3V3: J1.19 (GPIO10), U2.7 (FB2-17)
R1: U1.21 (R1), U2.50 (FB4-14), U4.21 (R1)
R1_3V3: J1.23 (GPIO11), U2.9 (FB1-5)
R2: U1.22 (R2), U2.51 (FB4-10), U4.22 (R2)
R2_3V3: J1.32 (GPIO12), U2.18 (FB1-10)
R3: U1.23 (R3), U2.52 (FB4-12), U4.23 (R3)
R3_3V3: J1.33 (GPIO13), U2.19 (FB1-15)
RGA1: U1.17 (RGA1), U4.17 (RGA1)
RGA2: U1.16 (RGA2), U4.16 (RGA2)
RGA3: U1.15 (RGA3), U4.15 (RGA3)
RGA4: U1.14 (RGA4), U4.14 (RGA4)
RGA5: U1.13 (RGA5), U4.13 (RGA5)
RGA6: U1.12 (RGA6), U4.12 (RGA6)
RGA7: U1.11 (RGA7), U4.11 (RGA7)
RGA8: U1.10 (RGA8), U4.10 (RGA8)
TCK_SPCLK: J1.38 (GPIO20), JTAG1.4, U2.16 (FB1-11/GCK2), U2.30 (TCK)
TDI_SPDATA: J1.27 (GPIO0), JTAG1.2, R1.1, U2.27 (FB3-9), U2.28 (TDI)
TDO: J1.18 (GPIO24), JTAG1.3, U2.53 (TDO)
TMS_CLKEN: J1.28 (GPIO1), JTAG1.1, U2.29 (TMS), U2.31 (FB3-3)
VCC: C1.2, J1.2 (VCC), J1.4 (VCC), J2.1, U1.19 (VCC), U3.3 (VI), U4.19 (VCC)
VERSION: J1.12 (GPIO18), U2.64 (FB2-9/GSR)
VSYNC: U2.48 (FB4-11)

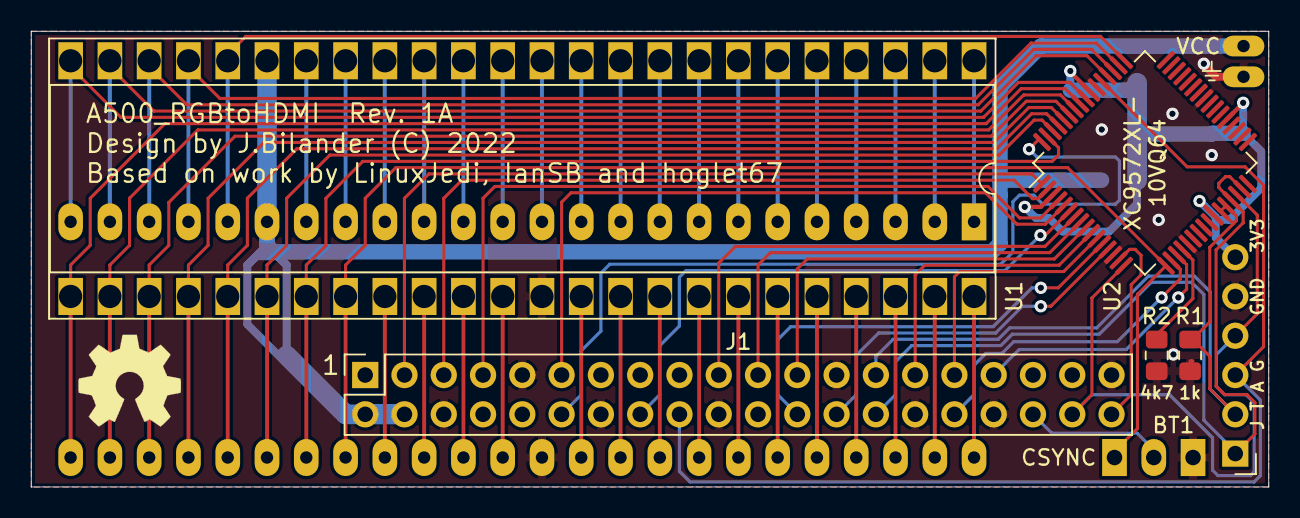
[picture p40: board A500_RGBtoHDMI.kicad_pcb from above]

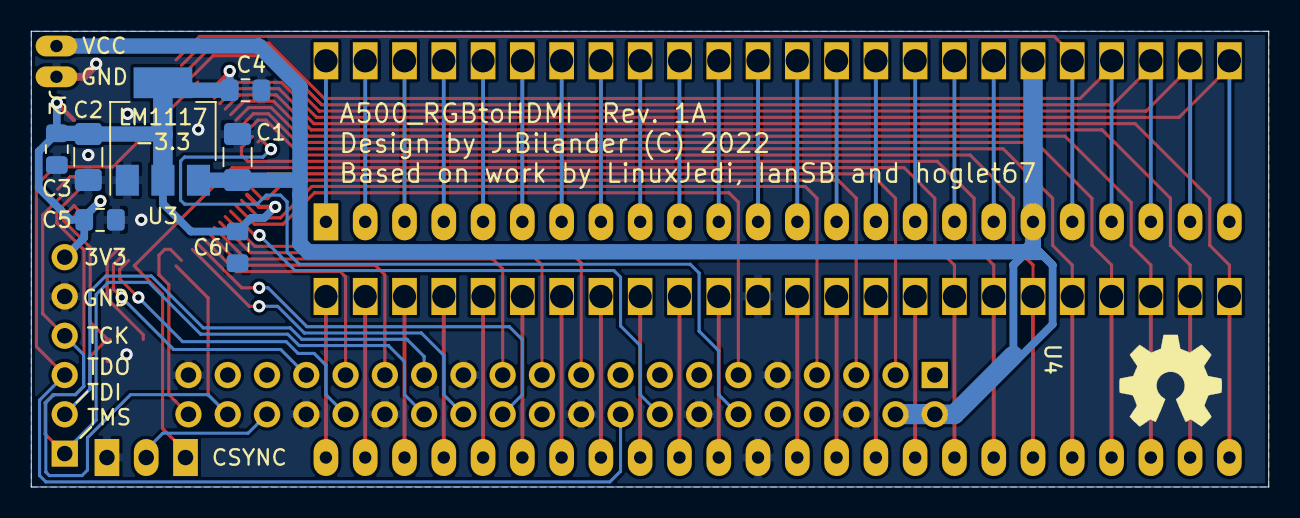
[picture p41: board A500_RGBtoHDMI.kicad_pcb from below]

Board: 2 copper layers, 80.0 x 29.5 mm, 17 parts (7 on the bottom side), 71 nets.

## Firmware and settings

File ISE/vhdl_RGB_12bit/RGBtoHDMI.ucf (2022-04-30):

# Global Clock Nets
NET "clk" BUFG=CLK;

# Global Clock Nets
NET "sp_clk" BUFG=CLK;

# 96MHz clock domain
NET "clk" TNM_NET = clk_period_grp_1;
TIMESPEC TS_clk_period_1 = PERIOD "clk_period_grp_1" 5.2ns HIGH;

# 10MHz clock domain
#NET "sp_clk" TNM_NET = clk_period_grp_2;
#TIMESPEC TS_clk_period_2 = PERIOD "clk_period_grp_2" 100ns HIGH;

NET "clk"       LOC = "P15";       # input  gpio21 (GCK1)

NET "R3_I"      LOC = "P52";       # input
NET "G3_I"      LOC = "P63";       # input
NET "B3_I"      LOC = "P59";       # input
NET "R2_I"      LOC = "P51";       # input
NET "G2_I"      LOC = "P62";       # input
NET "B2_I"      LOC = "P58";       # input
NET "R1_I"      LOC = "P50";       # input  (was gpio26)
NET "G1_I"      LOC = "P61";       # input  (was gpio19)
NET "B1_I"      LOC = "P57";       # input  (was gpio16)
NET "R0_I"      LOC = "P49";       # input  (was gpio27)
NET "G0_I"      LOC = "P60";       # input  (was gpio25)
NET "B0_I"      LOC = "P56";       # input  (was gpio24)

NET "csync_I"   LOC = "P17";       # input
NET "vsync_I"   LOC = "P48";       # input  (pin assigned but not connected)

NET "analog"    LOC = "P20";       # input  gpio22 (DETECT)

NET "version"   LOC = "P64";       # input  gpio18 (GSR)

NET "sp_clk"    LOC = "P16";       # input  gpio20 (GCK2) (TCK)
NET "sp_data"   LOC = "P27";       # input  gpio0  (input only) (TDI)
NET "sp_clken"  LOC = "P31";       # input  gpio1  (input only) (TMS)

NET "quad(0)"   LOC = "P1";        # output gpio2 (B0_3V3)
NET "quad(1)"   LOC = "P2";        # output gpio3 (B1_3V3)
NET "quad(2)"   LOC = "P4";        # output gpio4 (B2_3V3)
NET "quad(3)"   LOC = "P10";       # output gpio5 (B3_3V3)
NET "quad(4)"   LOC = "P11";       # output gpio6 (G0_3V3)
NET "quad(5)"   LOC = "P13";       # output gpio7 (G1_3V3)
NET "quad(6)"   LOC = "P12";       # output gpio8 (G2_3V3)
NET "quad(7)"   LOC = "P8";        # output gpio9 (G3_3V3)
NET "quad(8)"   LOC = "P7";        # output gpio10 (R0_3V3)
NET "quad(9)"   LOC = "P9";        # output gpio11 (R1_3V3)
NET "quad(10)"  LOC = "P18";       # output gpio12 (R2_3V3)
NET "quad(11)"  LOC = "P19";       # output gpio13 (R3_3V3)

NET "psync"     LOC = "P5";        # output gpio17 (Pi_CLK)
NET "csync"     LOC = "P6";        # output gpio23 (CSYNC_3V3)

NET "quad(0)"   SLOW;
NET "quad(1)"   SLOW;
NET "quad(2)"   SLOW;
NET "quad(3)"   SLOW;
NET "quad(4)"   SLOW;
NET "quad(5)"   SLOW;
NET "quad(6)"   SLOW;
NET "quad(7)"   SLOW;
NET "quad(8)"   SLOW;
NET "quad(9)"   SLOW;
NET "quad(10)"  SLOW;
NET "quad(11)"  SLOW;
NET "psync"     SLOW;
NET "csync"     SLOW;

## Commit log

2022-03-21 added KiCad files
    [A500_RGBtoHDMI.kicad_pcb, A500_RGBtoHDMI.sch]
2022-03-21 improved design
    [A500_RGBtoHDMI.kicad_pcb, A500_RGBtoHDMI.sch]
2022-03-21 more routing
    [A500_RGBtoHDMI.kicad_pcb, A500_RGBtoHDMI.sch]
2022-03-21 added networks to Pi-header
    [A500_RGBtoHDMI.kicad_pcb, A500_RGBtoHDMI.sch]
2022-03-21 added CPLD XC9572XL-VQ64 and did more layout and routing
    [A500_RGBtoHDMI.kicad_pcb, A500_RGBtoHDMI.sch]
2022-03-22 more routing and fixes
    [A500_RGBtoHDMI.kicad_pcb, A500_RGBtoHDMI.sch]
2022-03-23 more routing and small adjustments,fixes and improvements
    [A500_RGBtoHDMI.kicad_pcb, A500_RGBtoHDMI.sch]
2022-03-24 added LDO LM1117 3.3V fixed output
    [A500_RGBtoHDMI.kicad_pcb, A500_RGBtoHDMI.sch]
2022-03-24 added 100nF decoupling caps to CPLDs 3V3-inputs
    [A500_RGBtoHDMI.kicad_pcb, A500_RGBtoHDMI.sch]
2022-03-24 added a two-pin power header VCC/GND
    [A500_RGBtoHDMI.kicad_pcb, A500_RGBtoHDMI.sch]
2022-03-25 added Button-jumper (BT1) with 3V3-pull-up resistor
    [A500_RGBtoHDMI.kicad_pcb, A500_RGBtoHDMI.sch]
2022-03-25 added DETECT-signal with pull-down resistor
    [A500_RGBtoHDMI.kicad_pcb, A500_RGBtoHDMI.sch]
2022-03-26 added 3D-model of RPi Zero
    [A500_RGBtoHDMI.kicad_pcb]
2022-03-27 add CSYNC-PinHeader for Rev3 A500-mobos
    [A500_RGBtoHDMI.kicad_pcb, A500_RGBtoHDMI.sch]
2022-03-27 removed pull-up resistor on BT1 (gpio16), not needed
    [A500_RGBtoHDMI.kicad_pcb, A500_RGBtoHDMI.sch]
2022-03-27 some via and silkscreen fixes
    [A500_RGBtoHDMI.kicad_pcb]
2022-03-28 removed hole offset for VCC-header, and some silkscreen fix
    [A500_RGBtoHDMI.kicad_pcb]
2022-03-28 silkscreen fix
    [A500_RGBtoHDMI.kicad_pcb]
2022-04-30 added schematic pdf
2022-04-30 New pin assignments for VQ64 package

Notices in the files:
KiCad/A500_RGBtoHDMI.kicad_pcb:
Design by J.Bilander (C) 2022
